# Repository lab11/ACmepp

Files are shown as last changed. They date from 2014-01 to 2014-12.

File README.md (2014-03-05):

AC Power Meters
===============

This repository contains code and hardware for a set of AC power meters.

ACme++
------

ACme++ is an updated version of the [ACme](http://acme.eecs.berkeley.edu) device.
The major change is a switch from the Epic platform (MSP430F1611 and CC2420) to
the CC2538 system on chip. Other changes include putting the relay on the phase
wire (instead of neutral) and a smaller AC-DC power supply.

While ACme++ is a wireless power meter in its own right, it was designed to be 
a prototype for the ultra-space-constrained PowerCube device.

PowerCube
---------

PowerCube is a one cubic inch power meter. It is designed to unobtrusively fit
on a power strip. This requires using six PCBs arranged in a cube with very
strategically placed components.

Software
--------

Software for the ACme++ is written on top of ContikiOS.

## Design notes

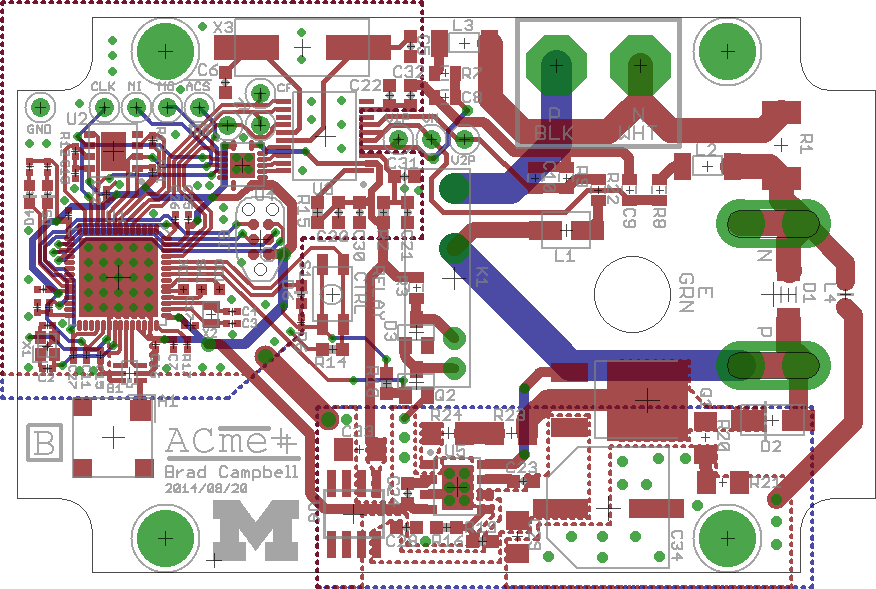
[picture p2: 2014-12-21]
hardware/ACme++/rev_b/ACme++_pcb.png

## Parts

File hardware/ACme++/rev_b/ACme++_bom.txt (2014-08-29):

# Bill of Materials
# Converted from ACme++_bom.xlsx
# Generated by bom_to_text.py

Qty  Value                           Device                          Package                          Parts                                        Description                                                       DIGIKEY             MOUSER                NEWARK   RICHARDSON_RFPD  McMASTER-CARR
1    FRACTUS-2.4GHZ-FR05-S1-N-0-001  FRACTUS-2.4GHZ-FR05-S1-N-0-001  FRACTUS-ANTENNA-FR05-S1-N-0-001  A1                                           Fractus Reach Xtend                                                                                                  FR05-S1-N-0001B  
1    2450BM15A0002                   2450BM15A0002                   2450BM                           B1                                           BALUN JTI MATCHED ZIGBEE                                          712-1536-1-ND                                                       
2    12pF                            CAPACITOR                       0402-CAP                         C1, C2                                       Capacitor                                                         445-1236-1-ND                                                       
2    22pF                            CAPACITOR                       0402-CAP                         C3, C4                                       Capacitor                                                         490-5868-1-ND                                                       
2    22pF                            CAP0603-CAP                     0603-CAP                         C5, C6                                       Capacitor                                                         445-1273-1-ND                                                       
1    220pF                           CAPACITOR                       0402-CAP                         C7                                           Capacitor                                                         445-1251-1-ND                                                       
3    33nF                            CAP0805                         0805-CAP                         C8, C9, C10                                  Capacitor                                                         478-1389-1-ND                                                       
9    0.1uF                           CAPACITOR                       0402-CAP                         C11, C12, C13, C14, C15, C16, C17, C18, C19  Capacitor                                                         445-1265-1-ND                                                       
5    0.1uF                           CAP0603-CAP                     0603-CAP                         C20, C21, C22, C23, C24                      Capacitor                                                         445-1316-1-ND                                                       
3    1uF                             CAPACITOR                       0402-CAP                         C25, C26, C27                                Capacitor                                                         445-4998-1-ND                                                       
1    1uF                             CAP0603-CAP                     0603-CAP                         C28                                          Capacitor                                                         445-5956-1-ND                                                       
1    1uF                             CAP1206                         1206-CAP                         C29                                          Capacitor                                                         445-1381-1-ND                                                       
3    10uF                            CAP0603-CAP                     0603-CAP                         C30, C31, C32                                Capacitor                                                         1276-1119-1-ND                                                      
1    47uF                            CAP1206                         1206-CAP                         C33                                          Capacitor                                                         399-5508-1-ND                                                       
1    470uF                           CAP_EEE-FP1E471AP               CAP_SM_10MM                      C34                                          Surface mount low ESR cap.                                        PCE4440CT-ND                                                        
1    SMAJ_TVS                        SMAJ_TVS                        DO214_TVS                        D1                                                                                                             SMAJ250CALFCT-ND                                                    
1    S1G                             S1G                             DO-214AC                         D2                                           Diode 400V 1A SMA                                                 S1GFSCT-ND                                                          
1    DIODE_MMBD914                   DIODE_MMBD914                   SOT-23                           D3                                           DIODE SML SIG 100V 0.2A SOT23-3                                   MMBD914FSCT-ND                                                      
1    RED                             LED0603                         LED-0603                         D4                                           LEDs                                                              160-1835-1-ND                                                       
1    GREEN                           LED0603                         LED-0603                         D5                                           LEDs                                                              160-1834-1-ND                                                       
1    BLUE                            LED0603                         LED-0603                         D6                                           LEDs                                                              160-1837-1-ND                                                       
1    S216S01F                        S216S01F                        RELAY_SX16S0X                    K1                                           RELAY SSR 240VAC 16A TRIAC 4-SIP                                  425-2413-5-ND       852-S216S01F          14N9591                   
1    35F0121-0SR-10                  35F0121-0SR-10                  35F0102                          L1                                           FERRITE 10A 42 OHMS @ 10 MHZ SMD                                  240-2520-1-ND                                                       
2    EMI_SUPRESSION_FERRITE_BEAD     EMI_SUPRESSION_FERRITE_BEAD     L1806                            L2, L3                                       FERRITE 300MA 150 OHM 1806 SMD                                    240-2418-1-ND                                                       
1    MPZ2012S300A                    MPZ2012S300A                    0805                             L4                                           FERRITE CHIP 30 OHM 6A 0805                                       445-1566-1-ND                                                       
1    STGD5NB120SZT4                  STGD5NB120SZT4                  DPAK                             Q1                                           5 A - 1200 V - low drop internally clamped IGBT                   497-4352-1-ND                                                       
1    FDV301N                         FDV301N                         SOT-23                           Q2                                                                                                             FDV301NCT-ND                                                        
1    0.001                           RESISTOR2512                    R2512                            R1                                           Resistor                                                          P1.0TCT-ND                                                          
1    10                              RESISTOR0603-RES                0603-RES                         R2                                           Resistor                                                          RHM10.0CFCT-ND                                                      
1    330                             RESISTOR0805-RES                0805-RES                         R3                                           Resistor                                                          RHM330KCT-ND                                                        
3    470                             RESISTOR                        0402-RES                         R4, R5, R6                                   Resistor                                                          RHM470BHCT-ND                                                       
3    1k                              RESISTOR0805-RES                0805-RES                         R7, R8, R9                                   Resistor                                                          P16058CT-ND                                                         
1    2.2k                            RESISTOR                        0402-RES                         R10                                          Resistor                                                          RHM2.2KCECT-ND                                                      
3    4.7k                            RESISTOR                        0402-RES                         R11, R12, R13                                Resistor                                                          RHM4.7KCECT-ND                                                      
2    10k                             RESISTOR0603-RES                0603-RES                         R14, R15                                     Resistor                                                          RHM10.0KCFCT-ND                                                     
1    12.4k                           RESISTOR0603-RES                0603-RES                         R16                                          Resistor                                                          RHM12.4KCFCT-ND                                                     
1    56k                             RESISTOR                        0402-RES                         R17                                          Resistor                                                          RHM56KBHCT-ND                                                       
1    100k                            RESISTOR0603-RES                0603-RES                         R18                                          Resistor                                                          RHM100KCGCT-ND                                                      
1    113k                            RESISTOR0603-RES                0603-RES                         R19                                          Resistor                                                          RHM113KCFCT-ND                                                      
2    200k                            RESISTOR1206                    1206-RES                         R20, R21                                     Resistor                                                          P200KALCT-ND                                                        
1    499k                            RESISTOR0805-RES                0805-RES                         R22                                          Resistor                                                          P499KCCT-ND                                                         
2    510k                            RESISTOR1206                    1206-RES                         R23, R24                                     Resistor                                                          P510KALCT-ND                                                        
1    EVQP2                           EVQP2                           EVQP2                            S1                                                                                                             P11084SCT-ND                                                        
1    TEST_POINT_0.040IN              TEST_POINT_0.040IN              TESTPOINT_0.040IN                TP1                                          0.040in Test Point Black                                          5001K-ND                                                            
3    TEST_POINT_0.040IN              TEST_POINT_0.040IN              TESTPOINT_0.040IN                TP2, TP3, TP4                                0.040in Test Point Blue                                           5117K-ND                                                            
1    TEST_POINT_0.040IN              TEST_POINT_0.040IN              TESTPOINT_0.040IN                TP5                                          0.040in Test Point Yellow                                         5004K-ND                                                            
3    TEST_POINT_0.040IN              TEST_POINT_0.040IN              TESTPOINT_0.040IN                TP6, TP7, TP8                                0.040in Test Point Green                                          5116K-ND                                                            
3    TEST_POINT_0.040IN              TEST_POINT_0.040IN              TESTPOINT_0.040IN                TP9, TP10, TP11                              0.040in Test Point Orange                                         5003K-ND                                                            
1    CC2538                          CC2538                          S-PVQFN-N56                      U1                                           A Powerful System-On-Chip for 2.4-GHz IEEE 802.15.4, 6LoWPAN      296-35797-1-ND      595-CC2538SF53RTQT    87W7713                   
1    FM25LBTDFN-8                    FM25LBTDFN-8                    TDFN-8                           U2                                           IC FRAM 4KBIT 10MHZ 8SOIC                                         FM25L04B-DGRA-ND    877-FM25L04B-DG                                 
1    ADE7753                         ADE7753                         SSOP-20                          U3                                           Single-Phase Multifunction Metering IC                            ADE7753ARSZRLCT-ND  584-ADE7753ARSZR      59K0984                   
1    TXB0104RGY                      TXB0104RGY                      S-PVQFN-N14                      U4                                           4-BIT BIDIRECTIONAL VOLTAGE-LEVEL TRANSLATOR                      296-21930-1-ND                                                      
1    SR086SG-G                       SR086SG-G                       SR086                            U5                                           Adjustable Off-Line Inductorless Switching Regulator                                  689-SR086SG-G                                   
1    TDA3664AT                       TDA3664AT                       SOIC_8                           U6                                           Very low dropout voltage/quiescent current 5 V voltage regulator  568-3310-1-ND       771-TDA3664ATN1118                              
1    EPSON-FA-128                    EPSON-FA-128                    FA-128                           X1                                           MHz RANGE CRYSTAL UNIT                                            SER3800CT-ND        732-FA128-32F20X-K3                             
1    FC-12M32.7680KA-A3              FC-12M32.7680KA-A3              FC-12M                           X2                                           kHz RANGE CRYSTAL UNIT                                            SER3672CT-ND        732-FC-12M-32.76KAA3                            
1    ECS-35-17-5PX-TR                ECS-35-17-5PX-TR                CSM-7X                           X3                                           CRYSTAL 3.579545MHZ 17PF SMD                                      XC1234CT-ND         520-CSM357-17-X                                 
1    ENCLOSURE                       PPB-11860-BK                                                                                                  BOX ABS 3.09X2.09X1.65" BLK                                       377-1709-ND                                                         
0    ENCLOSURE                       PPB-11860-WT                                                                                                  BOX ABS 3.09X2.09X1.65" WHT                                       377-1710-ND                                                         
1    SOCKET                          739W-X2/03                                                                                                    OUTLET PWR NEMA 5-15R SNAPIN/IDC                                  Q228-ND                                                             
0    14AWG Black                     6717 BK005                                                                                                    HOOK-UP STRND 14AWG BLACK 100'                                    6717 BK005-ND                                                       
0    14AWG Green                     6717 GR005                                                                                                    HOOK-UP STRND 14AWG GREEN 100'                                    6717 GR005-ND                                                       
0    14AWG White                     6717 WH005                                                                                                    HOOK-UP STRND 14AWG WHITE 100'                                    6717 WH005-ND                                                       
4    #4 Screw                                                                                                                                      #4 3/16" Panhead Self-Tapping Screws                                                                                                  92470a106

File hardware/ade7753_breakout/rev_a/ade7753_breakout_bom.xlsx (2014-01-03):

Part | Value | Device | Package | Description | Distributor | Quantity | Part# | Custom Part# | Price | min price break | Notes
C1, C2, C3, C4 | 33n | CAP0805 | C0805 | Capacitor | DigiKey | 4 | 478-3769-1-ND |  | 0.363 | 100
C5, C7, C9 | 0.1u | CAP0805 | C0805 | Capacitor | DigiKey | 3 | 478-5721-1-ND |  | 0.209 | 100
C6, C8, C10 | 10u | CAP0805 | C0805 | Capacitor | DigiKey | 3 | 478-5165-1-ND |  | 0.33 | 100
C11, C12 | 22p | C-USC0603 | C0603 | CAPACITOR, America | DigiKey | 2 | 478-5771-1-ND |  | 0.66 | 100
J1, J2 |  | M02PTH | 1X02 | Header 2 | DigiKey | 2 | A31112-ND |  | 0.2 | 25
J3 | M10" | M10" | 1X10 | Header 10 | DigiKey | 1 | A30844-ND |  | 0.54 | 25
R1, R2, R3, R4 | 1k | R-US_R0603 | R0603 | RESISTOR, American | DigiKey | 4 | RG16P1.0KBCT-ND |  | 0.409 | 50
R5 | 10 | R-US_R0603 | R0603 | RESISTOR, American | DigiKey | 1 | CRT0603-BY-10R0ELFCT-ND |  | 0.25 | 10
R6, R7 | 499k | R-US_R0805 | R0805 | RESISTOR, American | DigiKey | 2 | RG20P499KBCT-ND |  | 0.409 | 100
U1 | ADE7753 | ADE7753 | SSOP20 |  | DigiKey | 1 | ADE7753ARSZ-ND |  | 4.31 | 25
Y1 | 3.579 MHz | CRYSTALHC49S | HC49/S | CRYSTAL | DigiKey | 1 | 887-1000-ND |  | 0.46 | 100

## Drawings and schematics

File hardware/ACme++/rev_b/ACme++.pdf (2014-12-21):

# Programmer Header

## TC2030-CC2538-BL-NL

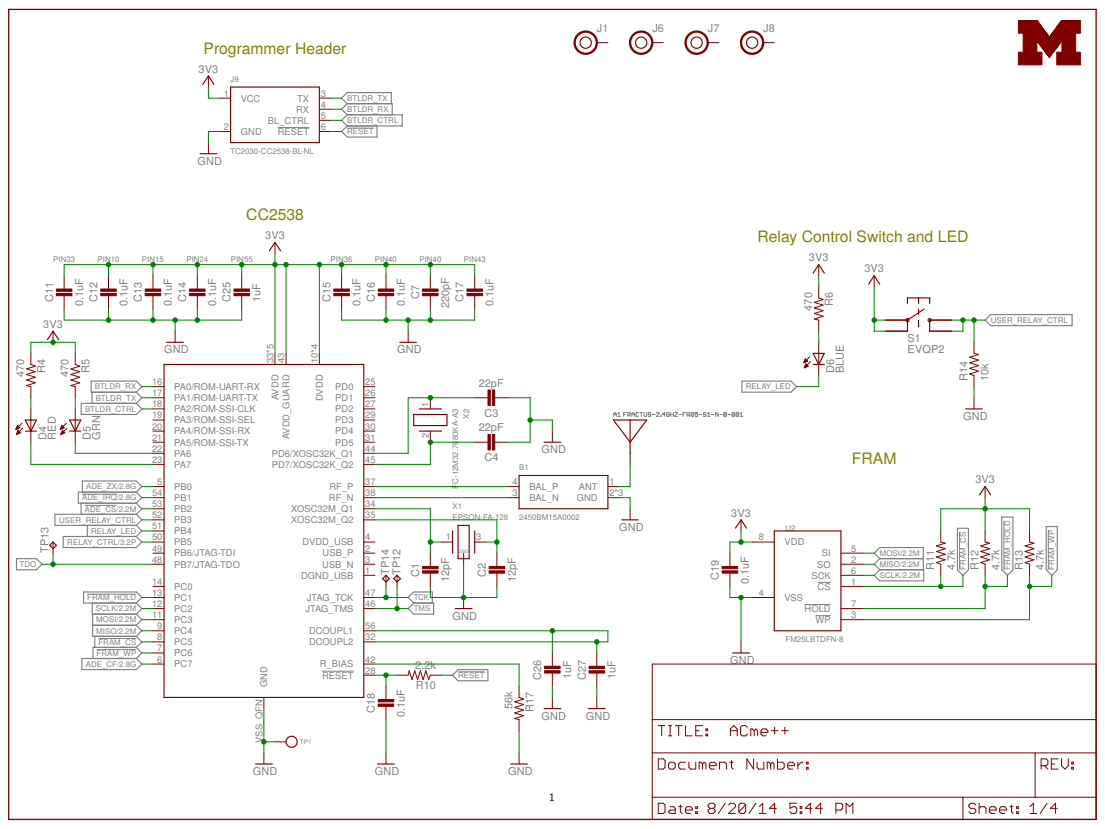
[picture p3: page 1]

Relay Control Switch and LED

32
42

# ADE7753 Power Measurement

5V0

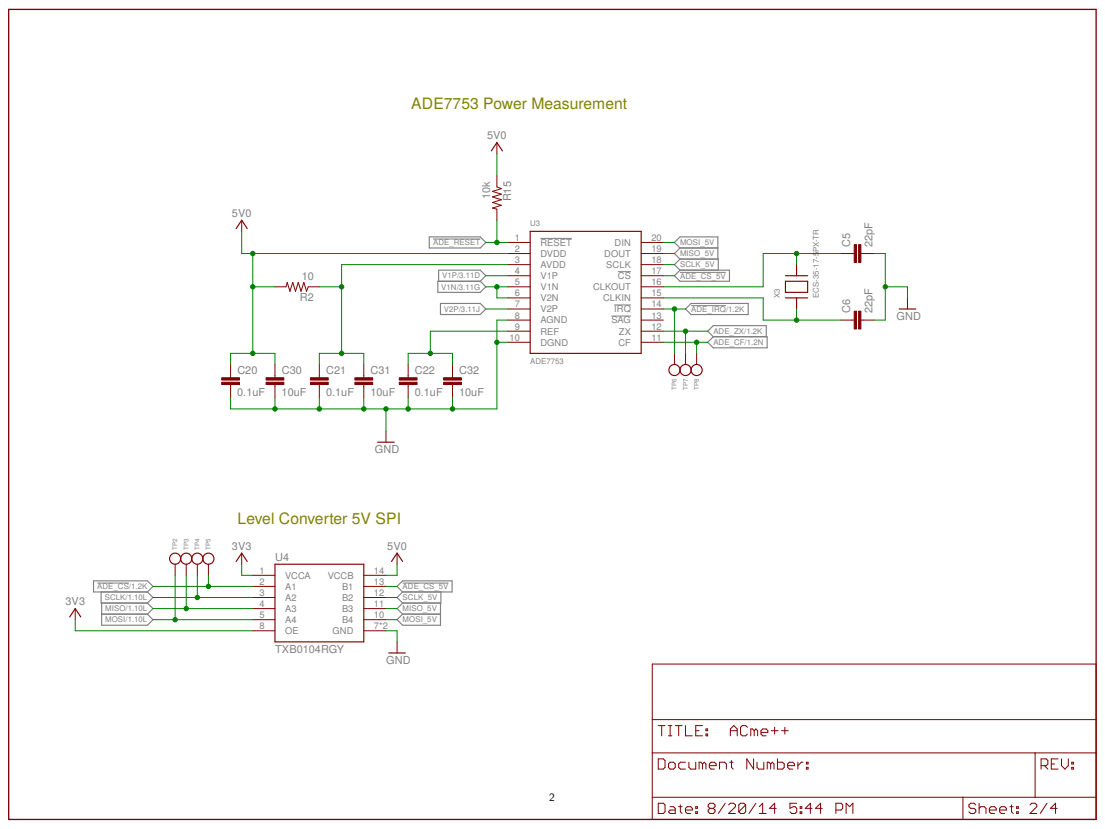
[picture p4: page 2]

# Sense Resistor

# Metering Conditioning

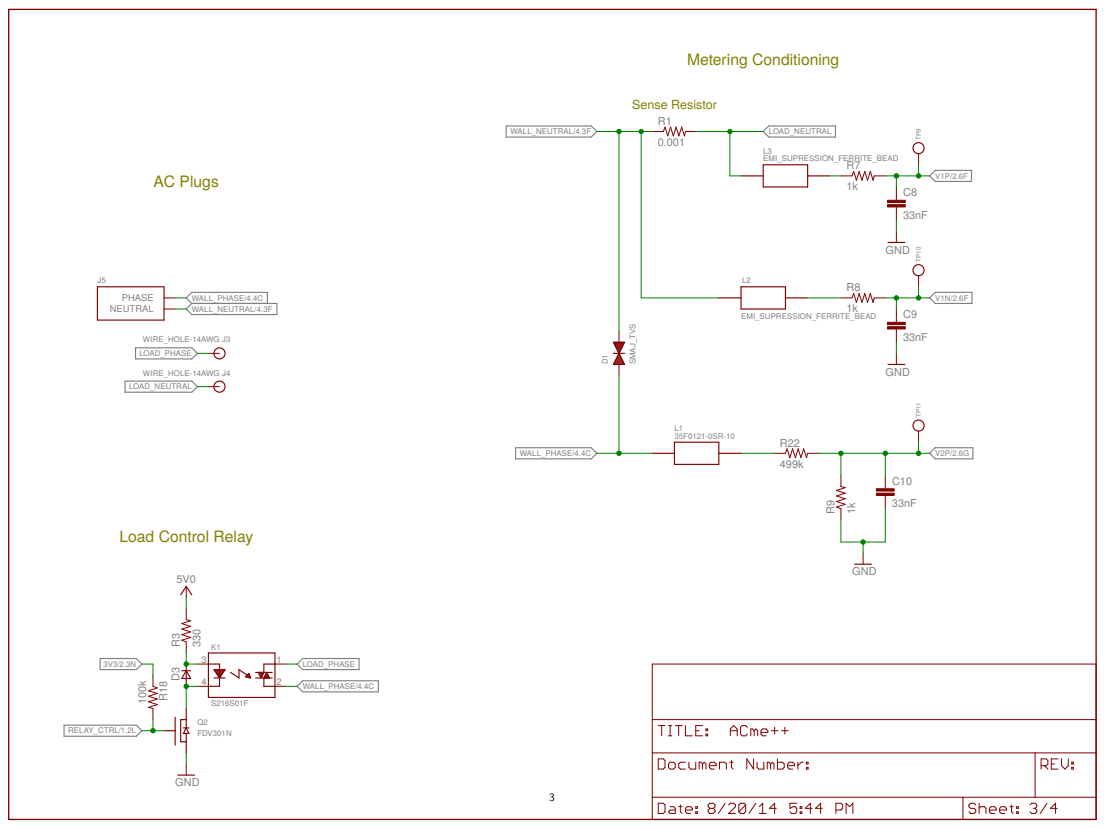
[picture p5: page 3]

## Nominally 12.6 V AC-DC Converter

## Note: Need half-wave rectifier here

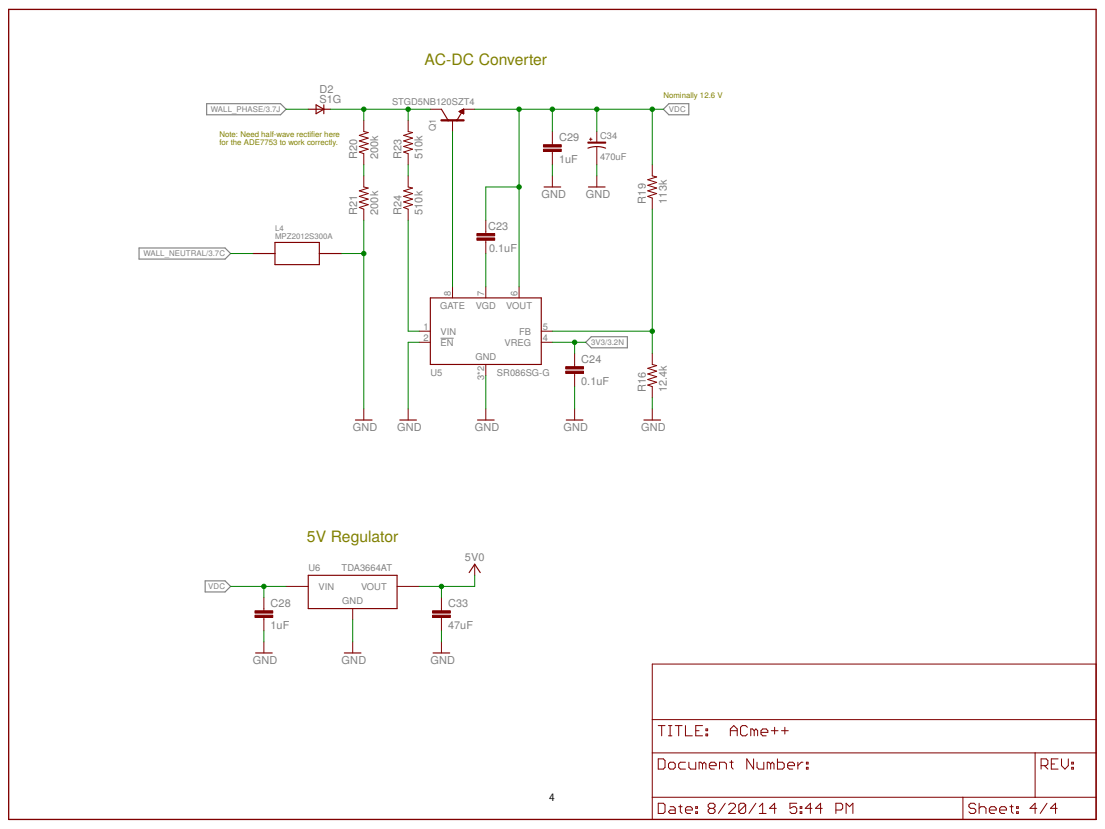
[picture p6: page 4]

for the ADE7753 to work correctly.

# Top and Bottom Layers

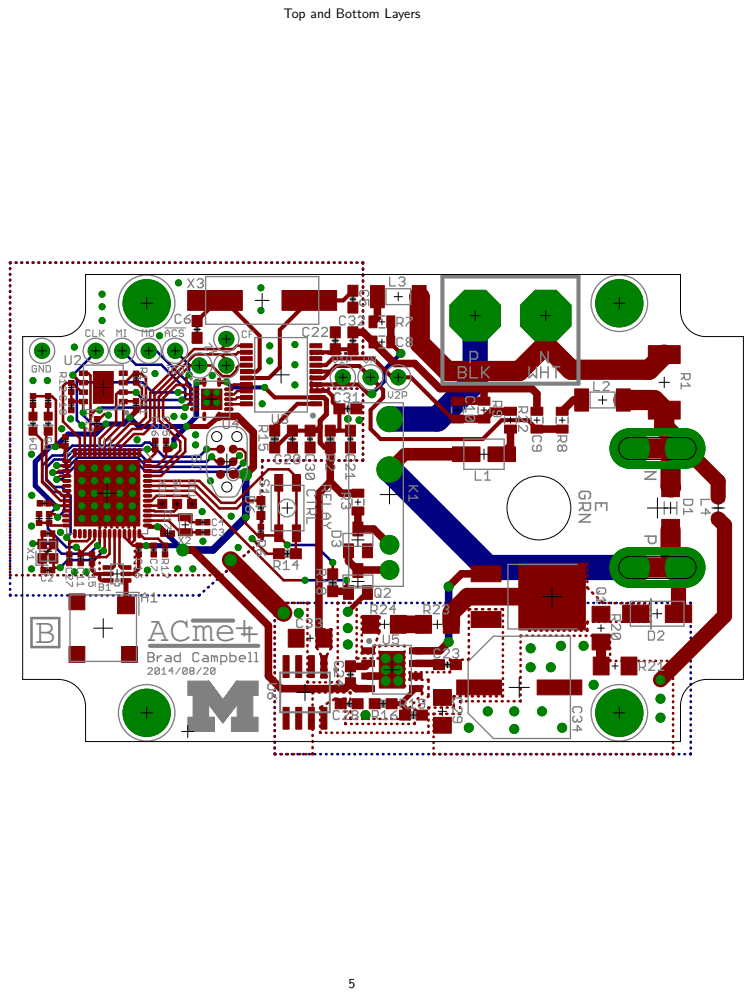
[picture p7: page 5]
ACme+

# Top Layer

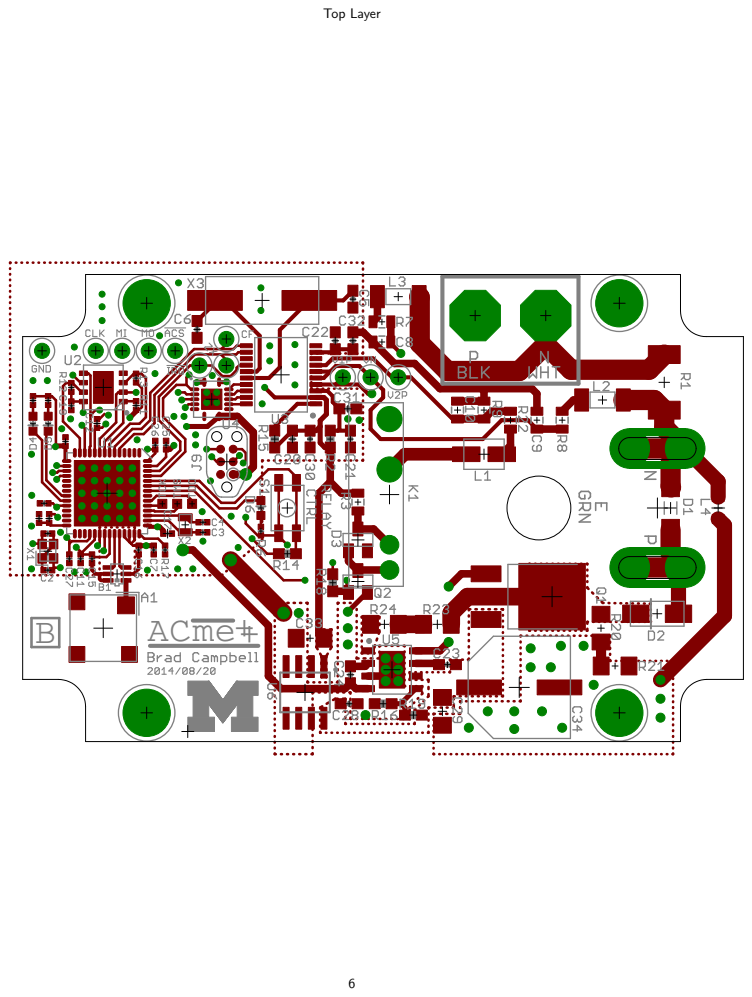
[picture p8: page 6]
ACme+

# Bottom Layer

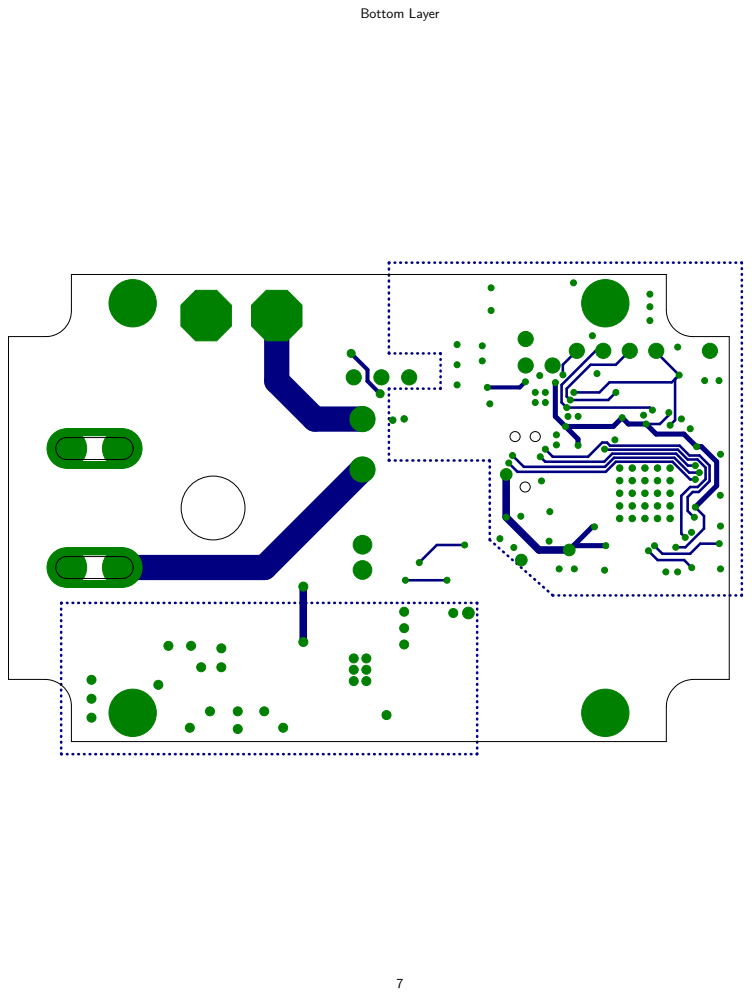
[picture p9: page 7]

# Top Copper Layer

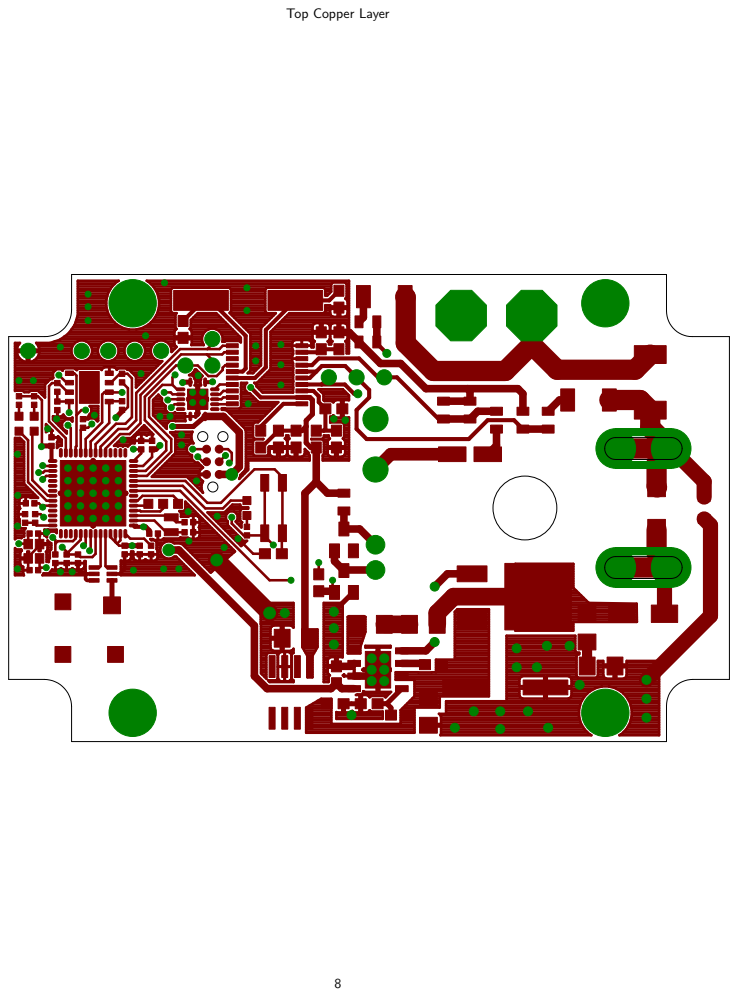
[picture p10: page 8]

# Bottom Copper Layer

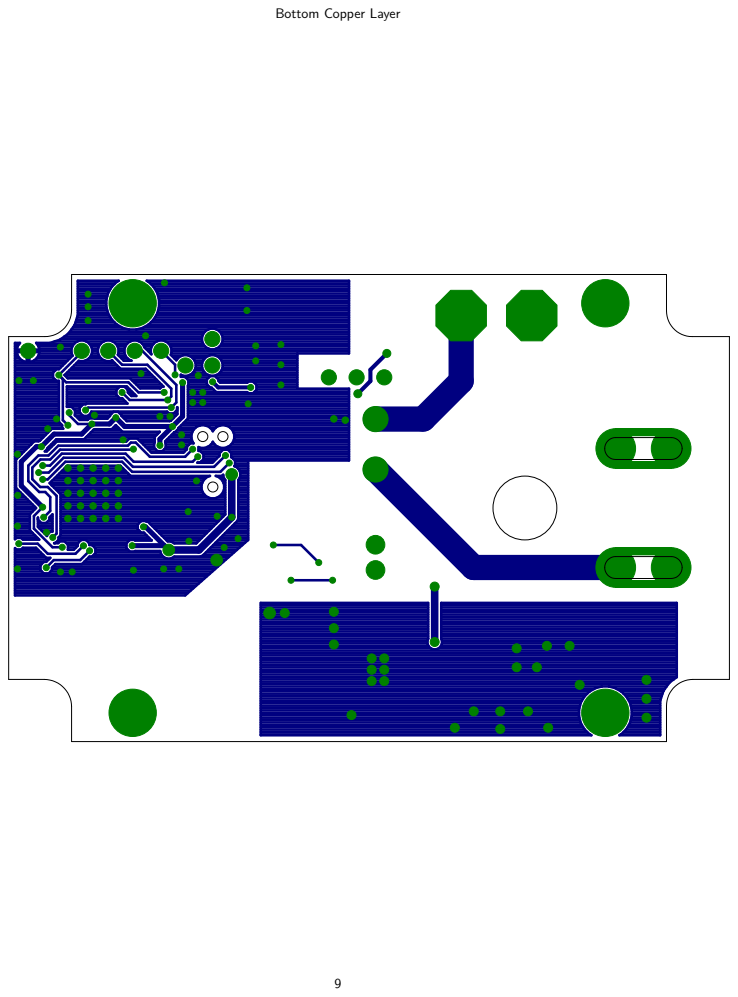
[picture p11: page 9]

# Top Paste Layer with Silkscreen

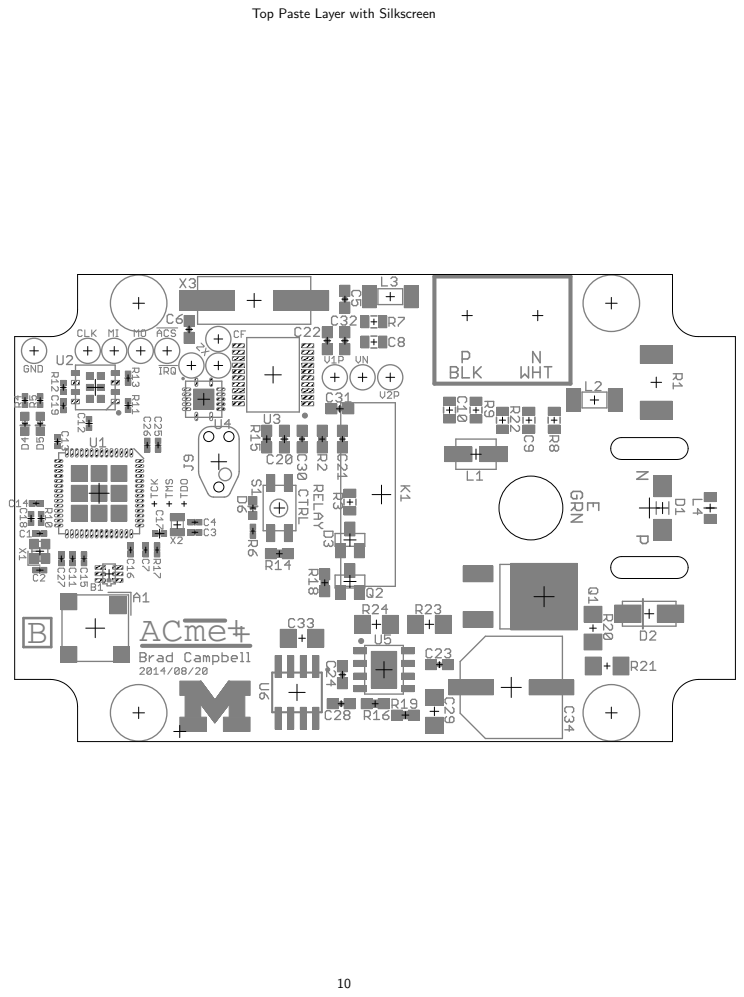
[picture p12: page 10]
ACme+

# Bottom Paste Layer with Silkscreen

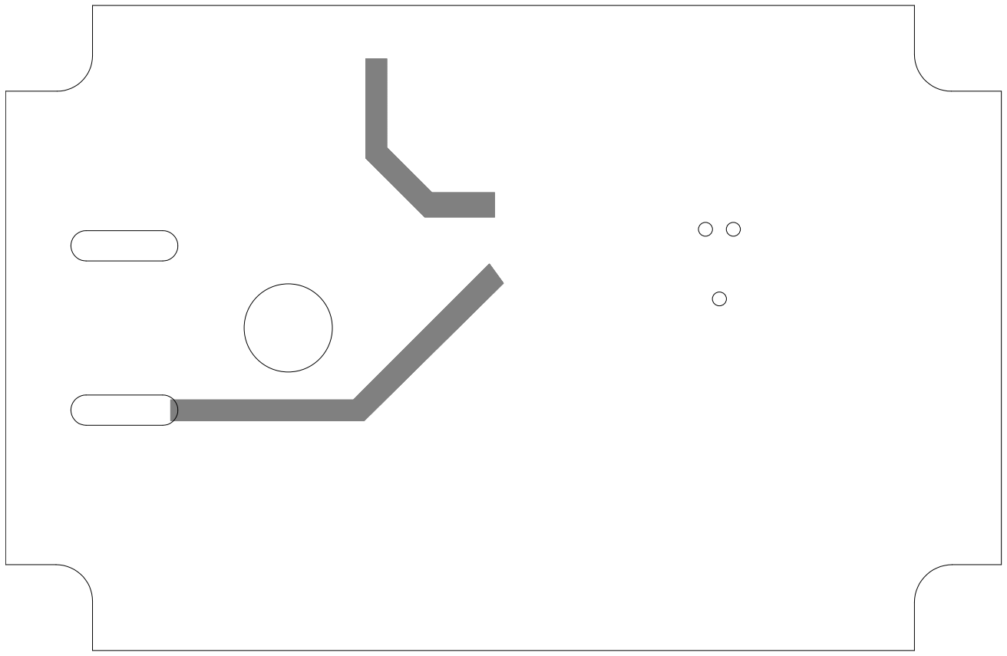
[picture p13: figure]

# Top and Bottom Layers 1:1 Scale

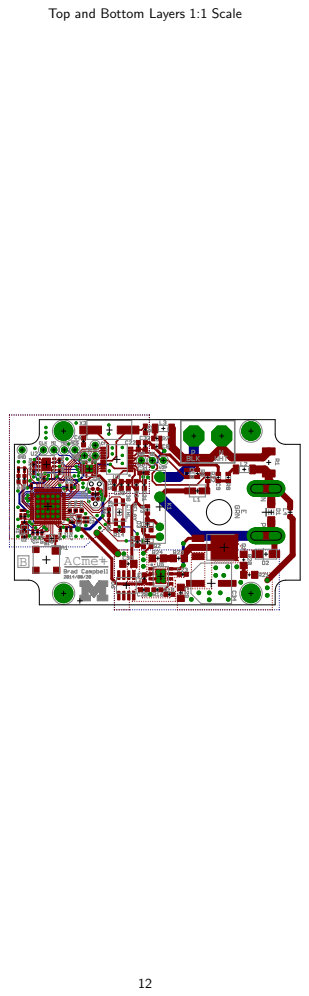
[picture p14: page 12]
ACme+

# Top Layer 1:1 Scale


# Bottom Copper Layer 1:1 Scale


Qty | Value | Device | Package | Parts | Description | DIGIKEY | MOUSER | NEWARK RICHARDSON_RFPD McMASTER-CARR
| 1 FRACTUS-2.4GHZ-FR05-S1-N-0-001 | FRACTUS-2.4GHZ-FR05-S1-N-0-001 | FRACTUS-ANTENNA-FR05-S1-N-0-001 | A1 | Fractus Reach Xtend | | | FR05-S1-N-0001B
| 1 2450BM15A0002 | 2450BM15A0002 | 2450BM | B1 | BALUN JTI MATCHED ZIGBEE | 712-1536-1-ND
| 2 12pF | CAPACITOR | 0402-CAP | C1, C2 | Capacitor | 445-1236-1-ND
| 2 22pF | CAPACITOR | 0402-CAP | C3, C4 | Capacitor | 490-5868-1-ND
| 2 22pF | CAP0603-CAP | 0603-CAP | C5, C6 | Capacitor | 445-1273-1-ND
| 1 220pF | CAPACITOR | 0402-CAP | C7 | Capacitor | 445-1251-1-ND
| 3 33nF | CAP0805 | 0805-CAP | C8, C9, C10 | Capacitor | 478-1389-1-ND
| 9 0.1uF | CAPACITOR | 0402-CAP | C11, C12, C13, C14, C15, C16, C17, C18, C19 | Capacitor | 445-1265-1-ND
| 5 0.1uF | CAP0603-CAP | 0603-CAP | C20, C21, C22, C23, C24 | Capacitor | 445-1316-1-ND
| 3 1uF | CAPACITOR | 0402-CAP | C25, C26, C27 | Capacitor | 445-4998-1-ND
| 1 1uF | CAP0603-CAP | 0603-CAP | C28 | Capacitor | 445-5956-1-ND
| 1 1uF | CAP1206 | 1206-CAP | C29 | Capacitor | 445-1381-1-ND
| 3 10uF | CAP0603-CAP | 0603-CAP | C30, C31, C32 | Capacitor | 1276-1119-1-ND
| 1 47uF | CAP1206 | 1206-CAP | C33 | Capacitor | 399-5508-1-ND
| 1 470uF | CAP_EEE-FP1E471AP | CAP_SM_10MM | C34 | Surface mount low ESR cap. | PCE4440CT-ND
| 1 SMAJ_TVS | SMAJ_TVS | DO214_TVS | D1 | | SMAJ250CALFCT-ND
| 1 S1G | S1G | DO-214AC | D2 | Diode 400V 1A SMA | S1GFSCT-ND
| 1 DIODE_MMBD914 | DIODE_MMBD914 | SOT-23 | D3 | DIODE SML SIG 100V 0.2A SOT23-3 | MMBD914FSCT-ND
| 1 RED | LED0603 | LED-0603 | D4 | LEDs | 160-1835-1-ND
| 1 GREEN | LED0603 | LED-0603 | D5 | LEDs | 160-1834-1-ND
| 1 BLUE | LED0603 | LED-0603 | D6 | LEDs | 160-1837-1-ND
| 1 S216S01F | S216S01F | RELAY_SX16S0X | K1 | RELAY SSR 240VAC 16A TRIAC 4-SIP | 425-2413-5-ND | 852-S216S01F | 14N9591
| 1 35F0121-0SR-10 | 35F0121-0SR-10 | 35F0102 | L1 | FERRITE 10A 42 OHMS @ 10 MHZ SMD | 240-2520-1-ND
| 2 EMI_SUPRESSION_FERRITE_BEAD | EMI_SUPRESSION_FERRITE_BEAD | L1806 | L2, L3 | FERRITE 300MA 150 OHM 1806 SMD | 240-2418-1-ND
| 1 MPZ2012S300A | MPZ2012S300A | 0805 | L4 | FERRITE CHIP 30 OHM 6A 0805 | 445-1566-1-ND
| 1 STGD5NB120SZT4 | STGD5NB120SZT4 | DPAK | Q1 | 5 A - 1200 V - low drop internally clamped IGBT | 497-4352-1-ND
| 1 FDV301N | FDV301N | SOT-23 | Q2 | | FDV301NCT-ND
| 1 0.001 | RESISTOR2512 | R2512 | R1 | Resistor | P1.0TCT-ND
| 1 10 | RESISTOR0603-RES | 0603-RES | R2 | Resistor | RHM10.0CFCT-ND
| 1 330 | RESISTOR0805-RES | 0805-RES | R3 | Resistor | RHM330KCT-ND
| 3 470 | RESISTOR | 0402-RES | R4, R5, R6 | Resistor | RHM470BHCT-ND
| 3 1k | RESISTOR0805-RES | 0805-RES | R7, R8, R9 | Resistor | P16058CT-ND
| 1 2.2k | RESISTOR | 0402-RES | R10 | Resistor | RHM2.2KCECT-ND
| 3 4.7k | RESISTOR | 0402-RES | R11, R12, R13 | Resistor | RHM4.7KCECT-ND
| 2 10k | RESISTOR0603-RES | 0603-RES | R14, R15 | Resistor | RHM10.0KCFCT-ND
| 1 12.4k | RESISTOR0603-RES | 0603-RES | R16 | Resistor | RHM12.4KCFCT-ND
| 1 56k | RESISTOR | 0402-RES | R17 | Resistor | RHM56KBHCT-ND
| 1 100k | RESISTOR0603-RES | 0603-RES | R18 | Resistor | RHM100KCGCT-ND
| 1 113k | RESISTOR0603-RES | 0603-RES | R19 | Resistor | RHM113KCFCT-ND
| 2 200k | RESISTOR1206 | 1206-RES | R20, R21 | Resistor | P200KALCT-ND
| 1 499k | RESISTOR0805-RES | 0805-RES | R22 | Resistor | P499KCCT-ND
| 2 510k | RESISTOR1206 | 1206-RES | R23, R24 | Resistor | P510KALCT-ND
| 1 EVQP2 | EVQP2 | EVQP2 | S1 | | P11084SCT-ND
| 1 TEST_POINT_0.040IN | TEST_POINT_0.040IN | TESTPOINT_0.040IN | TP1 | 0.040in Test Point Black | 5001K-ND
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

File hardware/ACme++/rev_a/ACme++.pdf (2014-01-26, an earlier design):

# Programmer Header

DS2411


Relay Control Switch and LED

32
42

# ADE7753 Power Measurement

5V0


# Sense Resistor

# Metering Conditioning


## Nominally 12.6 V AC-DC Converter

# CD2320-BB11000


# Top and Bottom Layers

ACme+

# Top Layer

ACme+

# Bottom Layer


# Top Copper Layer


# Bottom Copper Layer


# Top Paste Layer with Silkscreen

ACme+

# Bottom Paste Layer with Silkscreen


# Top and Bottom Layers 1:1 Scale

ACme+

# Top Layer 1:1 Scale


# Bottom Copper Layer 1:1 Scale


Qty | Value | Device | Package | Parts | Description | DIGIKEY | MOUSER | NEWARK RICHARDSON_RFPD McMASTER-CARR
| 1 FRACTUS-2.4GHZ-FR05-S1-N-0-001 | FRACTUS-2.4GHZ-FR05-S1-N-0-001 | FRACTUS-ANTENNA-FR05-S1-N-0-001 | A1 | Fractus Reach Xtend | | | FR05-S1-N-0001B
| 1 2450BM15A0002 | 2450BM15A0002 | 2450BM | B1 | BALUN JTI MATCHED ZIGBEE | 712-1536-1-ND
| 2 12pF | CAPACITOR | 0402-CAP | C1, C2 | Capacitor | 445-1236-1-ND
| 2 22pF | CAPACITOR | 0402-CAP | C3, C4 | Capacitor | 490-5868-1-ND
| 2 22pF | CAP0603-CAP | 0603-CAP | C5, C6 | Capacitor | 445-1273-1-ND
| 1 220pF | CAPACITOR | 0402-CAP | C7 | Capacitor | 445-1251-1-ND
| 3 33nF | CAP0805 | 0805-CAP | C8, C9, C10 | Capacitor | 478-1389-1-ND
9 0.1uF | CAPACITOR | 0402-CAP | C11, C12, C13, C14, C15, C16, C17, C18, C19 Capacitor | 445-1265-1-ND
| 5 0.1uF | CAP0603-CAP | 0603-CAP | C20, C21, C22, C23, C24 | Capacitor | 445-1316-1-ND
| 3 1uF | CAPACITOR | 0402-CAP | C25, C26, C27 | Capacitor | 445-4998-1-ND
| 1 1uF | CAP0603-CAP | 0603-CAP | C28 | Capacitor | 445-5956-1-ND
| 1 1uF | CAP1206 | 1206-CAP | C29 | Capacitor | 445-1381-1-ND
| 3 10uF | CAP0603-CAP | 0603-CAP | C30, C31, C32 | Capacitor | 1276-1119-1-ND
| 1 47uF | CAP1206 | 1206-CAP | C33 | Capacitor | 399-5508-1-ND
| 1 470uF | CAP_EEE-FP1E471AP | CAP_SM_10MM | C34 | Surface mount low ESR cap. | PCE4440CT-ND
| 1 SMAJ_TVS | SMAJ_TVS | DO214_TVS | D1 | | SMAJ250CALFCT-ND
| 1 CD2320-BB11000 | CD2320-BB11000 | CD2320 | D2 | Bridge rectifier | CD2320-B11000CT-ND
| 1 DIODE_MMBD914 | DIODE_MMBD914 | SOT-23 | D3 | DIODE SML SIG 100V 0.2A SOT23-3 | MMBD914FSCT-ND
| 1 RED | LED0603 | LED-0603 | D4 | LEDs | 160-1835-1-ND
| 1 GREEN | LED0603 | LED-0603 | D5 | LEDs | 160-1834-1-ND
| 1 BLUE | LED0603 | LED-0603 | D6 | LEDs | 160-1837-1-ND
| 1 AC-PLUG | AC-PLUG | AC_MALE_PINS | J1 | For use with Bud Industries Box: 377-1709-ND
| 1 TC2030-CTX-NL | TC2030-CTX-NL | TC2030-IDC-NL | J2 | Tag Connect footprint for ARM JTAG.
| 3 WIRE_HOLE-14AWG | WIRE_HOLE-14AWG | WIRE_HOLE-14AWG | J3, J4, J5 | Solder point for 14AWG wire
| 1 S216S01F | S216S01F | RELAY_SX16S0X | K1 | RELAY SSR 240VAC 16A TRIAC 4-SIP | 425-2413-5-ND | 852-S216S01F | 14N9591
| 1 35F0121-0SR-10 | 35F0121-0SR-10 | 35F0102 | L1 | FERRITE 10A 42 OHMS @ 10 MHZ SMD | 240-2520-1-ND
| 2 EMI_SUPRESSION_FERRITE_BEAD | EMI_SUPRESSION_FERRITE_BEAD | L1806 | L2, L3 | FERRITE 300MA 150 OHM 1806 SMD | 240-2418-1-ND
| 1 STGD5NB120SZT4 | STGD5NB120SZT4 | DPAK | Q1 | 5 A - 1200 V - low drop internally clamped IGBT | 497-4352-1-ND
| 1 FDV301N | FDV301N | SOT-23 | Q2 | | FDV301NCT-ND
| 1 0.001 | RESISTOR2512 | R2512 | R1 | Resistor | P1.0TCT-ND
| 1 10 | RESISTOR0603-RES | 0603-RES | R2 | Resistor | RHM10.0CFCT-ND
| 1 330 | RESISTOR0805-RES | 0805-RES | R3 | Resistor | RHM330KCT-ND
| 3 470 | RESISTOR | 0402-RES | R4, R5, R6 | Resistor | RHM470BHCT-ND
| 3 1k | RESISTOR0805-RES | 0805-RES | R7, R8, R9 | Resistor | P16058CT-ND
| 2 2.2k | RESISTOR | 0402-RES | R10, R11 | Resistor | RHM2.2KCECT-ND
| 3 4.7k | RESISTOR | 0402-RES | R12, R13, R14 | Resistor | RHM4.7KCECT-ND
| 2 10k | RESISTOR0603-RES | 0603-RES | R15, R16 | Resistor | RHM10.0KCFCT-ND
| 1 12.4k | RESISTOR0603-RES | 0603-RES | R17 | Resistor | RHM12.4KCFCT-ND
| 1 56k | RESISTOR | 0402-RES | R18 | Resistor | RHM56KBHCT-ND
| 1 100k | RESISTOR0603-RES | 0603-RES | R19 | Resistor | RHM100KCGCT-ND
| 1 113k | RESISTOR0603-RES | 0603-RES | R20 | Resistor | RHM113KCFCT-ND
| 2 200k | RESISTOR1206 | 1206-RES | R21, R22 | Resistor | P200KALCT-ND
| 1 499k | RESISTOR0805-RES | 0805-RES | R23 | Resistor | P499KCCT-ND
| 2 510k | RESISTOR1206 | 1206-RES | R24, R25 | Resistor | P510KALCT-ND
| 1 EVQP2 | EVQP2 | EVQP2 | S1 | | P11084SCT-ND
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

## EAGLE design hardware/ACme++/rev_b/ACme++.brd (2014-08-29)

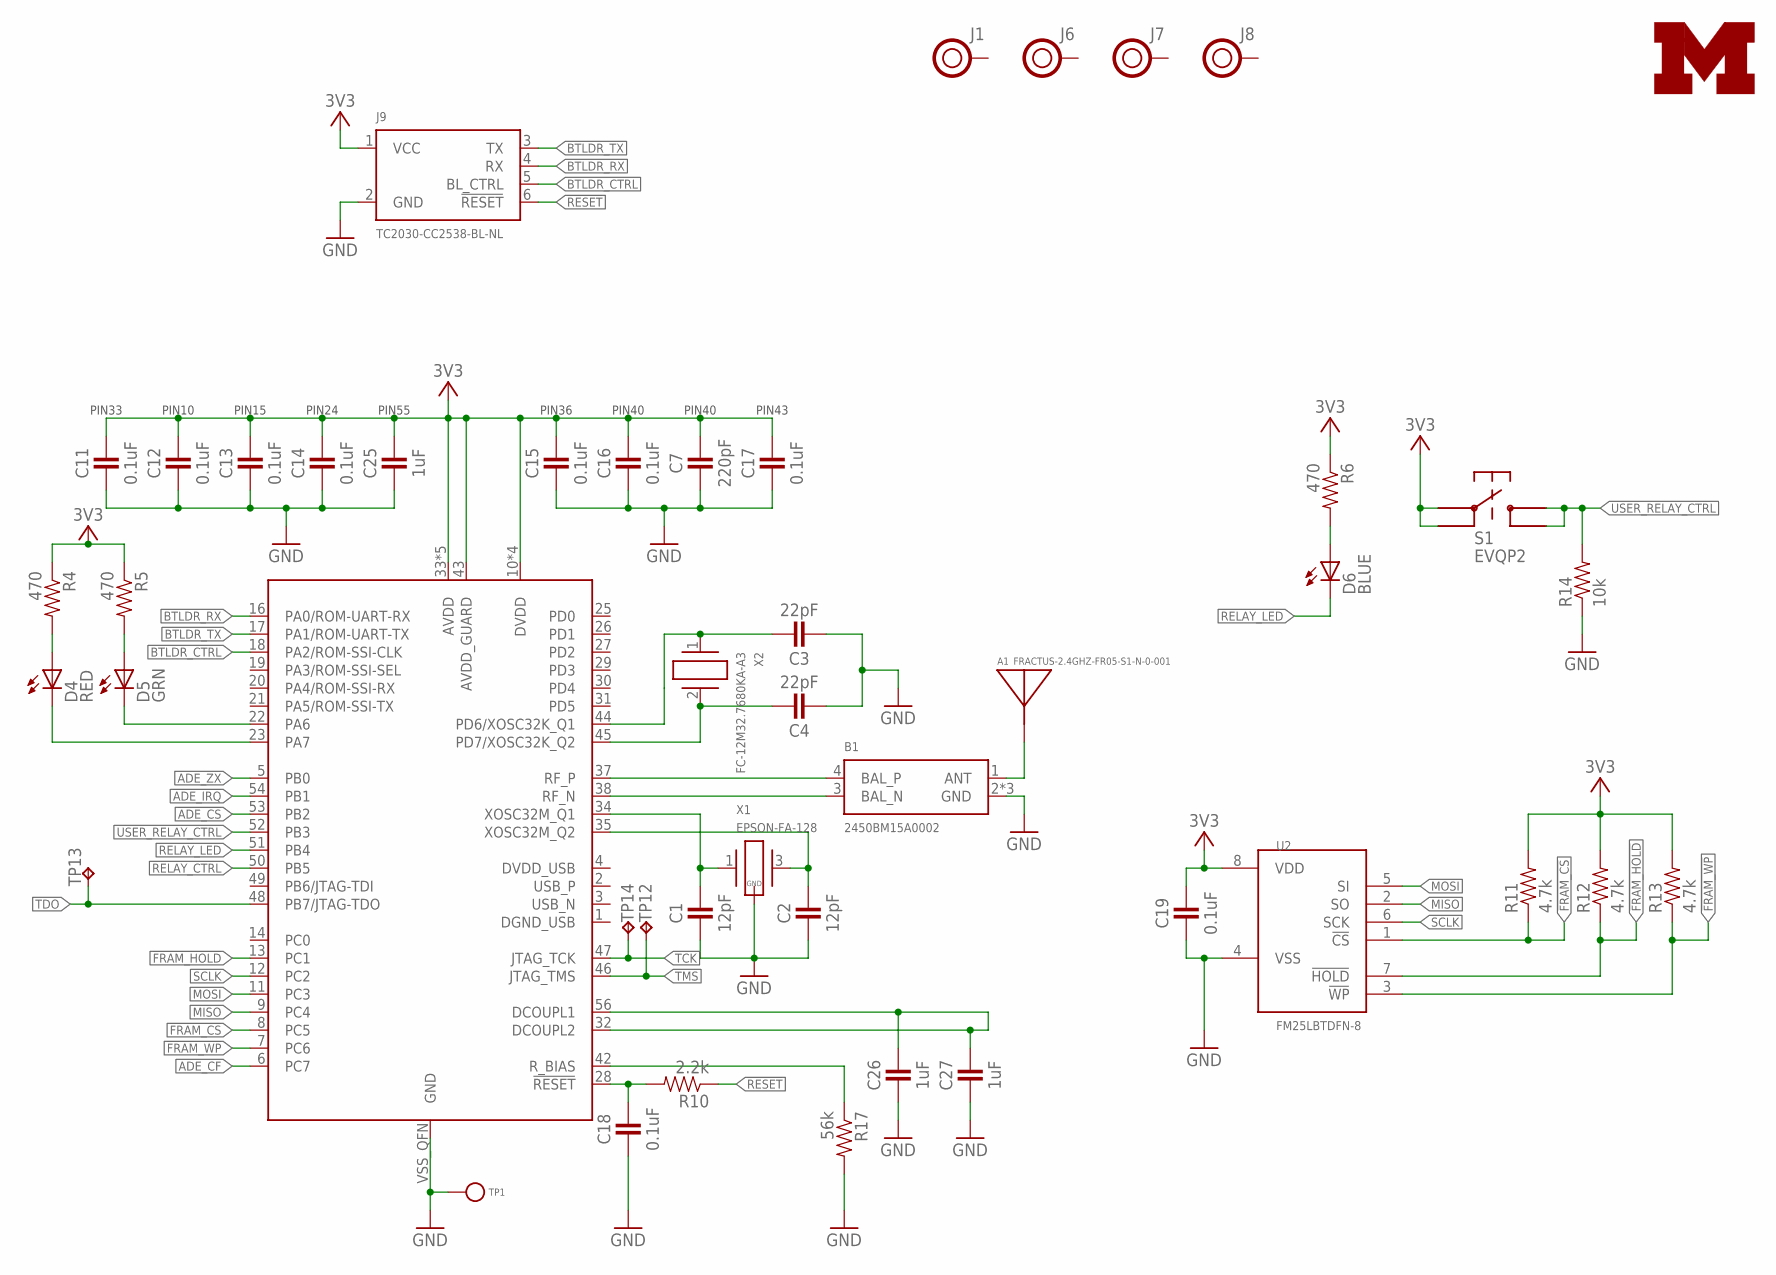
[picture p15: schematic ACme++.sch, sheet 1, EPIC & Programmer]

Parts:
A1: FRACTUS-2.4GHZ-FR05-S1-N-0-001; FRACTUS-ANTENNA-FR05-S1-N-0-001
B1: 2450BM15A0002; 2450BM
C1, C2: 12pF; 0402_CAP; DIGIKEY 445-1236-1-ND
C3, C4: 22pF; 0402_CAP; DIGIKEY 490-5868-1-ND
C7: 220pF; 0402_CAP; DIGIKEY 445-1251-1-ND
C11, C12, C13, C14, C15, C16, C17, C18, C19: 0.1uF; 0402_CAP; DIGIKEY 445-1265-1-ND
C25, C26, C27: 1uF; 0402_CAP; DIGIKEY 445-4998-1-ND
D4: RED; LED-0603; DIGIKEY 160-1835-1-ND
D5: GRN; LED-0603; DIGIKEY 160-1834-1-ND
D6: BLUE; LED-0603; DIGIKEY 160-1837-1-ND
J1, J6, J7, J8: HOLE; HOLE-0.125
J9: TC2030-CC2538-BL-NL; TC2030-IDC-NL
R4, R5, R6: 470; 0402_RES; DIGIKEY RHM470BHCT-ND
R10: 2.2k; 0402_RES; DIGIKEY RHM2.2KCECT-ND
R11, R12, R13: 4.7k; 0402_RES; DIGIKEY RHM4.7KCECT-ND
R14: 10k; 0603-RES; DIGIKEY RHM10.0KCFCT-ND
R17: 56k; 0402_RES; DIGIKEY RHM56KBHCT-ND
S1: EVQP2; DIGIKEY P11084SCT-ND
TP1: TEST_POINT_0.040IN; TESTPOINT_0.040IN
TP12, TP13, TP14: TPTP09SQ; TP09SQ
U1: CC2538; S-PVQFN-N56
U2: FM25LBTDFN-8; TDFN-8; DIGIKEY FM25L04B-DGRA-ND
U$3: UMICH_SOLID_MEDIUM; UMICH_SOLID_200MIL
X1: EPSON-FA-128; FA-128; DIGIKEY SER3800CT-ND
X2: FC-12M32.7680KA-A3; FC-12M

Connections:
3V3: C7.1, C11.1, C12.1, C13.1, C14.1, C15.1, C16.1, C17.1, C19.1, C25.1, J9.1 (VCC), R4.1, R5.1, R6.1, R11.2, R12.2, R13.2, S1.P$1, S1.P$3, U1.10 (DVDD), U1.15 (DVDD), U1.24 (DVDD), U1.33 (AVDD), U1.36 (AVDD), U1.39 (AVDD), U1.40 (AVDD), U1.41 (AVDD), U1.43 (AVDD_GUARD), U1.55 (DVDD), U2.8 (VDD); also elsewhere on the board
!ADE_CS: U1.53 (PB2); also elsewhere on the board
!ADE_IRQ: U1.54 (PB1); also elsewhere on the board
!FRAM_CS: R11.1, U1.8 (PC5), U2.1 (!CS)
!FRAM_HOLD: R12.1, U1.13 (PC1), U2.7 (!HOLD)
!FRAM_WP: R13.1, U1.7 (PC6), U2.3 (!WP)
!RESET: J9.6 (!RESET), R10.1
ADE_CF: U1.6 (PC7); also elsewhere on the board
ADE_ZX: U1.5 (PB0); also elsewhere on the board
ANTENNA: A1.1, B1.1 (ANT)
BTLDR_CTRL: J9.5 (BL_CTRL), U1.18 (PA2/ROM-SSI-CLK)
BTLDR_RX: J9.4 (RX), U1.16 (PA0/ROM-UART-RX)
BTLDR_TX: J9.3 (TX), U1.17 (PA1/ROM-UART-TX)
GND: B1.2 (GND), B1.5 (GND), B1.6 (GND), C1.2, C2.2, C3.2, C4.2, C7.2, C11.2, C12.2, C13.2, C14.2, C15.2, C16.2, C17.2, C18.2, C19.2, C25.2, C26.2, C27.2, J9.2 (GND), R14.1, R17.2, TP1.TESTPOINT, U1.VSS_QFN (GND), U2.4 (VSS), X1.2 (GND), X1.4 (GND); also elsewhere on the board
GREEN_LED: D5.C, U1.22 (PA6)
MISO: U1.9 (PC4), U2.2 (SO); also elsewhere on the board
MOSI: U1.11 (PC3), U2.5 (SI); also elsewhere on the board
unnamed: C26.1, C27.1, U1.32 (DCOUPL2), U1.56 (DCOUPL1)
unnamed: C18.1, R10.2, U1.28 (!RESET)
unnamed: C4.1, U1.45 (PD7/XOSC32K_Q2), X2.2
unnamed: C3.1, U1.44 (PD6/XOSC32K_Q1), X2.1
unnamed: R17.1, U1.42 (R_BIAS)
unnamed: C1.1, U1.34 (XOSC32M_Q1), X1.1
unnamed: C2.1, U1.35 (XOSC32M_Q2), X1.3 (2)
unnamed: D6.A, R6.2
unnamed: D4.A, R4.2
unnamed: D5.A, R5.2
RED_LED: D4.C, U1.23 (PA7)
RELAY_CTRL: U1.50 (PB5); also elsewhere on the board
RELAY_LED: D6.C, U1.51 (PB4)
RF_N: B1.3 (BAL_N), U1.38 (RF_N)
RF_P: B1.4 (BAL_P), U1.37 (RF_P)
SCLK: U1.12 (PC2), U2.6 (SCK); also elsewhere on the board
TCK: TP14.TP, U1.47 (JTAG_TCK)
TDO: TP13.TP, U1.48 (PB7/JTAG-TDO)
TMS: TP12.TP, U1.46 (JTAG_TMS)
USER_RELAY_CTRL: R14.2, S1.P$2, S1.P$4, U1.52 (PB3)

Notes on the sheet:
PIN10
PIN15
PIN24
PIN55
PIN33
PIN36
PIN40
PIN43

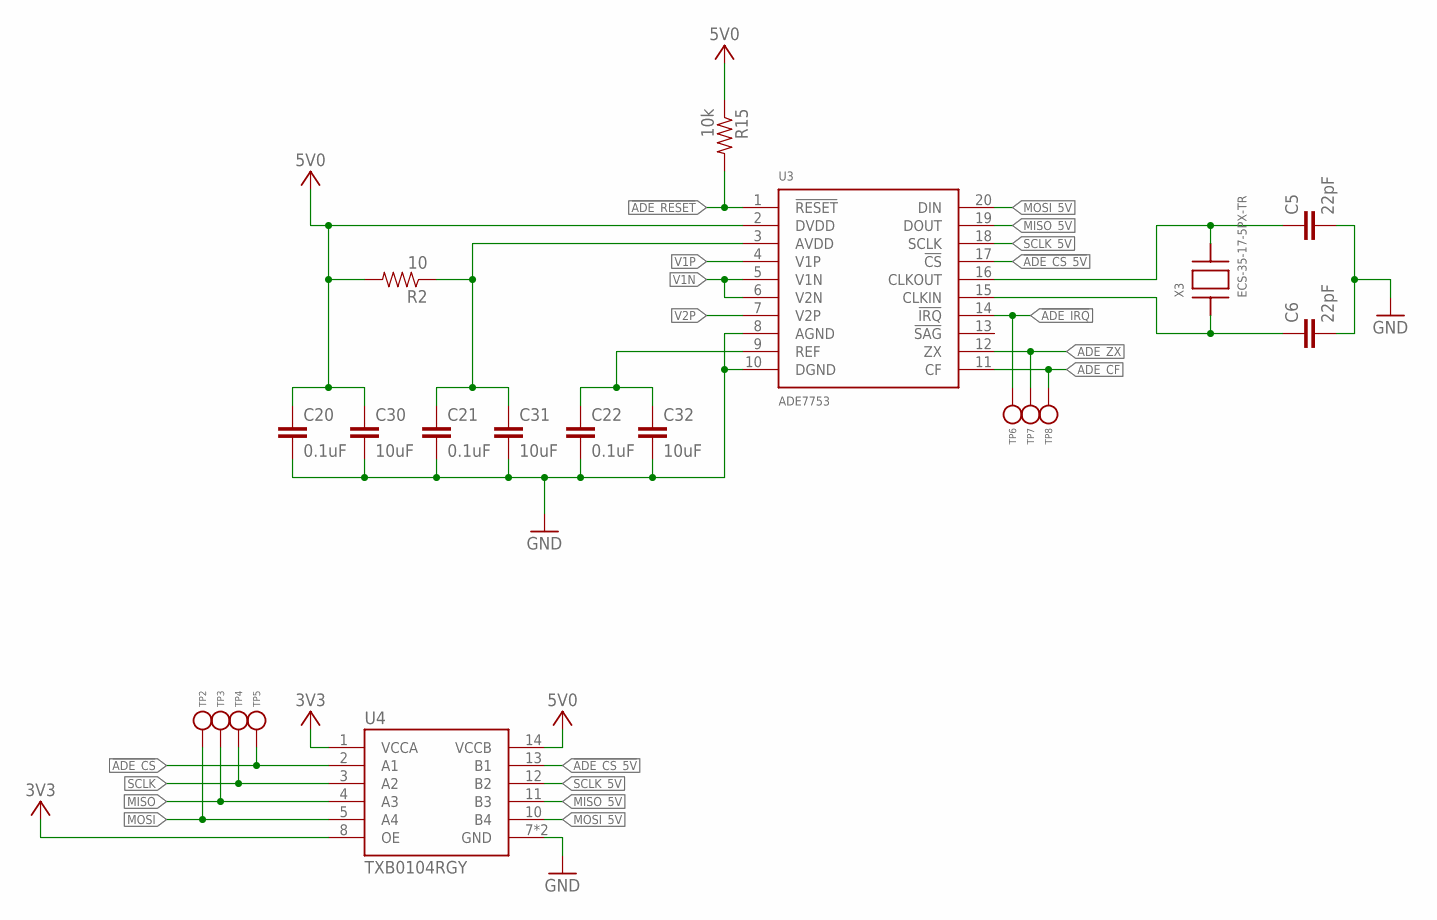
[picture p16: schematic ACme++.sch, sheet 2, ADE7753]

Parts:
C5, C6: 22pF; 0603-CAP; DIGIKEY 445-1273-1-ND
C20, C21, C22: 0.1uF; 0603-CAP; DIGIKEY 445-1316-1-ND
C30, C31, C32: 10uF; 0603-CAP; DIGIKEY 1276-1119-1-ND
R2: 10; 0603-RES; DIGIKEY RHM10.0CFCT-ND
R15: 10k; 0603-RES; DIGIKEY RHM10.0KCFCT-ND
TP2, TP3, TP4, TP5, TP6, TP7, TP8: TEST_POINT_0.040IN; TESTPOINT_0.040IN
U3: ADE7753; SSOP-20; MOUSER 584-ADE7753ARSZR
U4: TXB0104RGY; S-PVQFN-N14
X3: ECS-35-17-5PX-TR; CSM-7X

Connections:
3V3: U4.1 (VCCA), U4.8 (OE); also elsewhere on the board
5V0: C20.1, C30.1, R2.2, R15.1, U3.2 (DVDD), U4.14 (VCCB); also elsewhere on the board
!ADE_CS: TP5.TESTPOINT, U4.2 (A1); also elsewhere on the board
!ADE_CS_5V: U3.17 (!CS), U4.13 (B1)
!ADE_IRQ: TP6.TESTPOINT, U3.14 (!IRQ); also elsewhere on the board
!ADE_RESET: R15.2, U3.1 (!RESET)
ADE_AVDD: C21.1, C31.1, R2.1, U3.3 (AVDD)
ADE_CF: TP8.TESTPOINT, U3.11 (CF); also elsewhere on the board
ADE_ZX: TP7.TESTPOINT, U3.12 (ZX); also elsewhere on the board
GND: C5.2, C6.2, C20.2, C21.2, C22.2, C30.2, C31.2, C32.2, U3.8 (AGND), U3.10 (DGND), U4.7 (GND), U4.THERMALPAD (GND); also elsewhere on the board
MISO: TP3.TESTPOINT, U4.4 (A3); also elsewhere on the board
MISO_5V: U3.19 (DOUT), U4.11 (B3)
MOSI: TP2.TESTPOINT, U4.5 (A4); also elsewhere on the board
MOSI_5V: U3.20 (DIN), U4.10 (B4)
unnamed: C6.1, U3.15 (CLKIN), X3.1
unnamed: C22.1, C32.1, U3.9 (REF)
unnamed: C5.1, U3.16 (CLKOUT), X3.2
SCLK: TP4.TESTPOINT, U4.3 (A2); also elsewhere on the board
SCLK_5V: U3.18 (SCLK), U4.12 (B2)
V1N: U3.5 (V1N), U3.6 (V2N); also elsewhere on the board
V1P: U3.4 (V1P); also elsewhere on the board
V2P: U3.7 (V2P); also elsewhere on the board

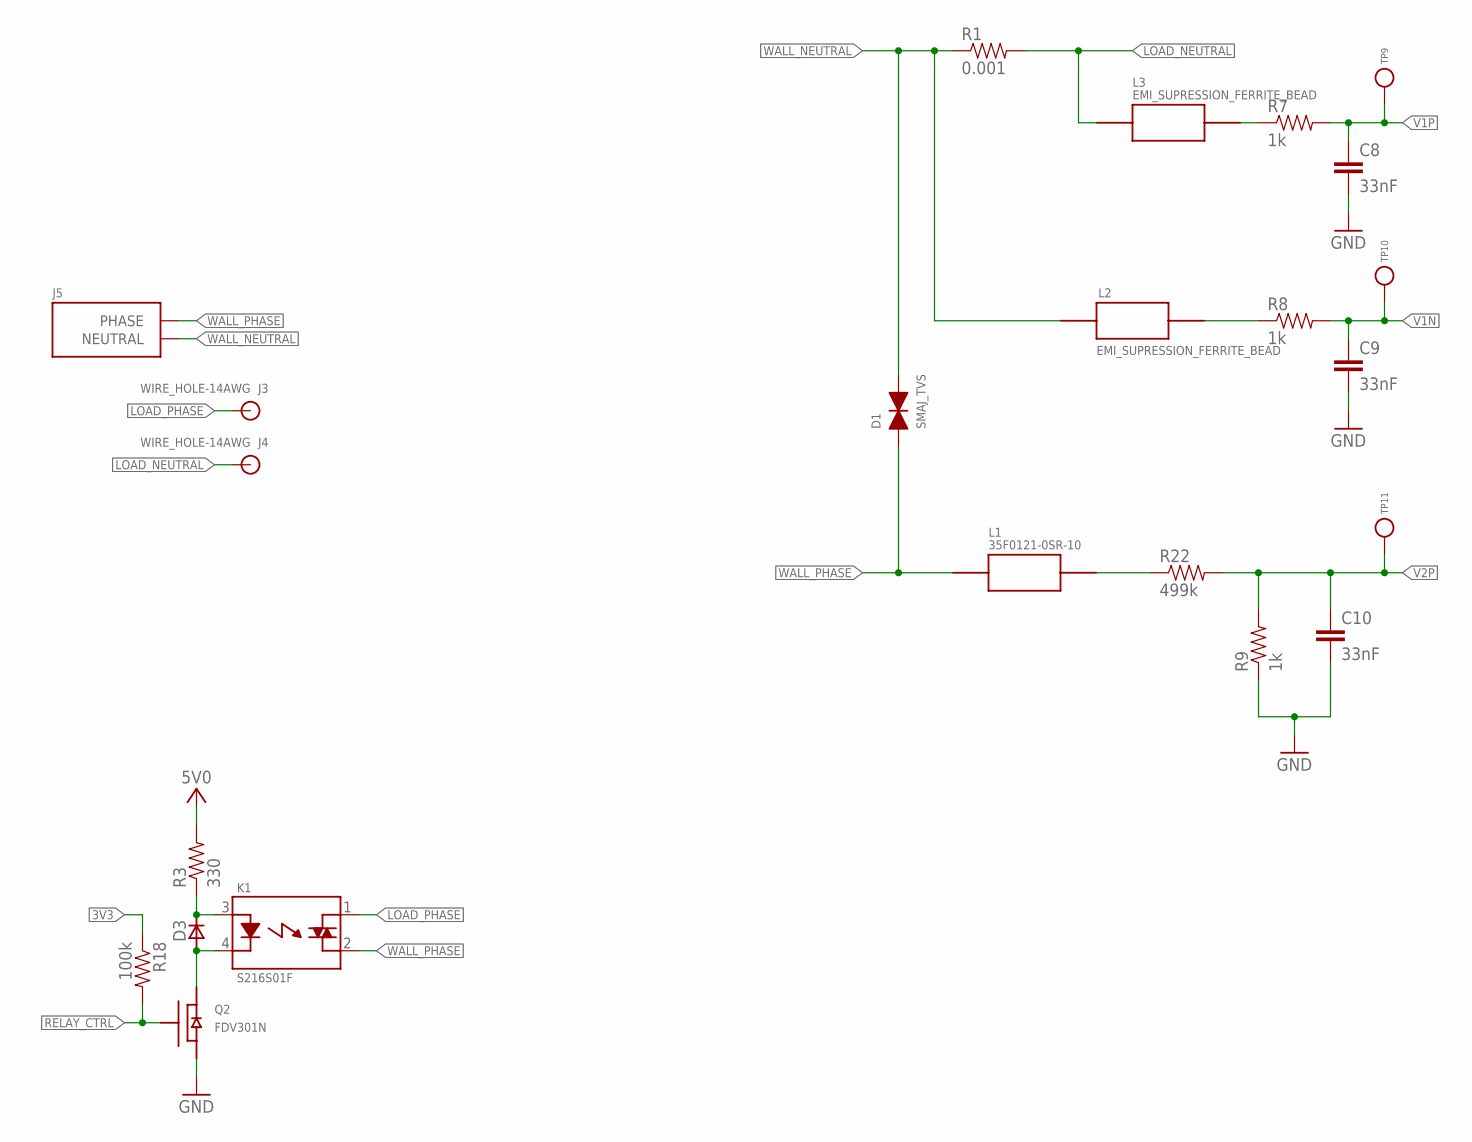
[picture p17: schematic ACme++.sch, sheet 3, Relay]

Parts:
C8, C9, C10: 33nF; 0805; DIGIKEY 478-1389-1-ND
D1: SMAJ_TVS; DO214_TVS
D3: DIODE_MMBD914; SOT-23
J3, J4: WIRE_HOLE-14AWG
J5: AC-PLUG-2; AC_MALE_PINS_2
K1: S216S01F; RELAY_SX16S0X
L1: 35F0121-0SR-10; 35F0102
L2, L3: EMI_SUPRESSION_FERRITE_BEAD; L1806
Q2: FDV301N; SOT-23
R1: 0.001; R2512; DIGIKEY P1.0TCT-ND
R3: 330; 0805; DIGIKEY RHM330KCT-ND
R7, R8, R9: 1k; 0805; DIGIKEY P16058CT-ND
R18: 100k; 0603-RES; DIGIKEY RHM100KCGCT-ND
R22: 499k; 0805; DIGIKEY P499KCCT-ND
TP9, TP10, TP11: TEST_POINT_0.040IN; TESTPOINT_0.040IN

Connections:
3V3: R18.1; also elsewhere on the board
5V0: R3.2; also elsewhere on the board
GND: C8.2, C9.2, C10.2, Q2.2 (S), R9.1; also elsewhere on the board
LOAD_NEUTRAL: J4.P$1, L3.P$1, R1.2
LOAD_PHASE: J3.P$1, K1.1
unnamed: D3.1 (ANNODE), K1.4, Q2.3 (D)
unnamed: D3.3 (CATHODE), K1.3, R3.1
unnamed: L2.P$2, R8.1
unnamed: L3.P$2, R7.1
unnamed: L1.2, R22.1
RELAY_CTRL: Q2.1 (G), R18.2; also elsewhere on the board
V1N: C9.1, R8.2, TP10.TESTPOINT; also elsewhere on the board
V1P: C8.1, R7.2, TP9.TESTPOINT; also elsewhere on the board
V2P: C10.1, R9.2, R22.2, TP11.TESTPOINT; also elsewhere on the board
WALL_NEUTRAL: D1.CATHODE, J5.NEUTRAL1 (NEUTRAL), J5.NEUTRAL2 (NEUTRAL), L2.P$1, R1.1; also elsewhere on the board
WALL_PHASE: D1.ANODE, J5.PHASE1 (PHASE), J5.PHASE2 (PHASE), K1.2, L1.1; also elsewhere on the board

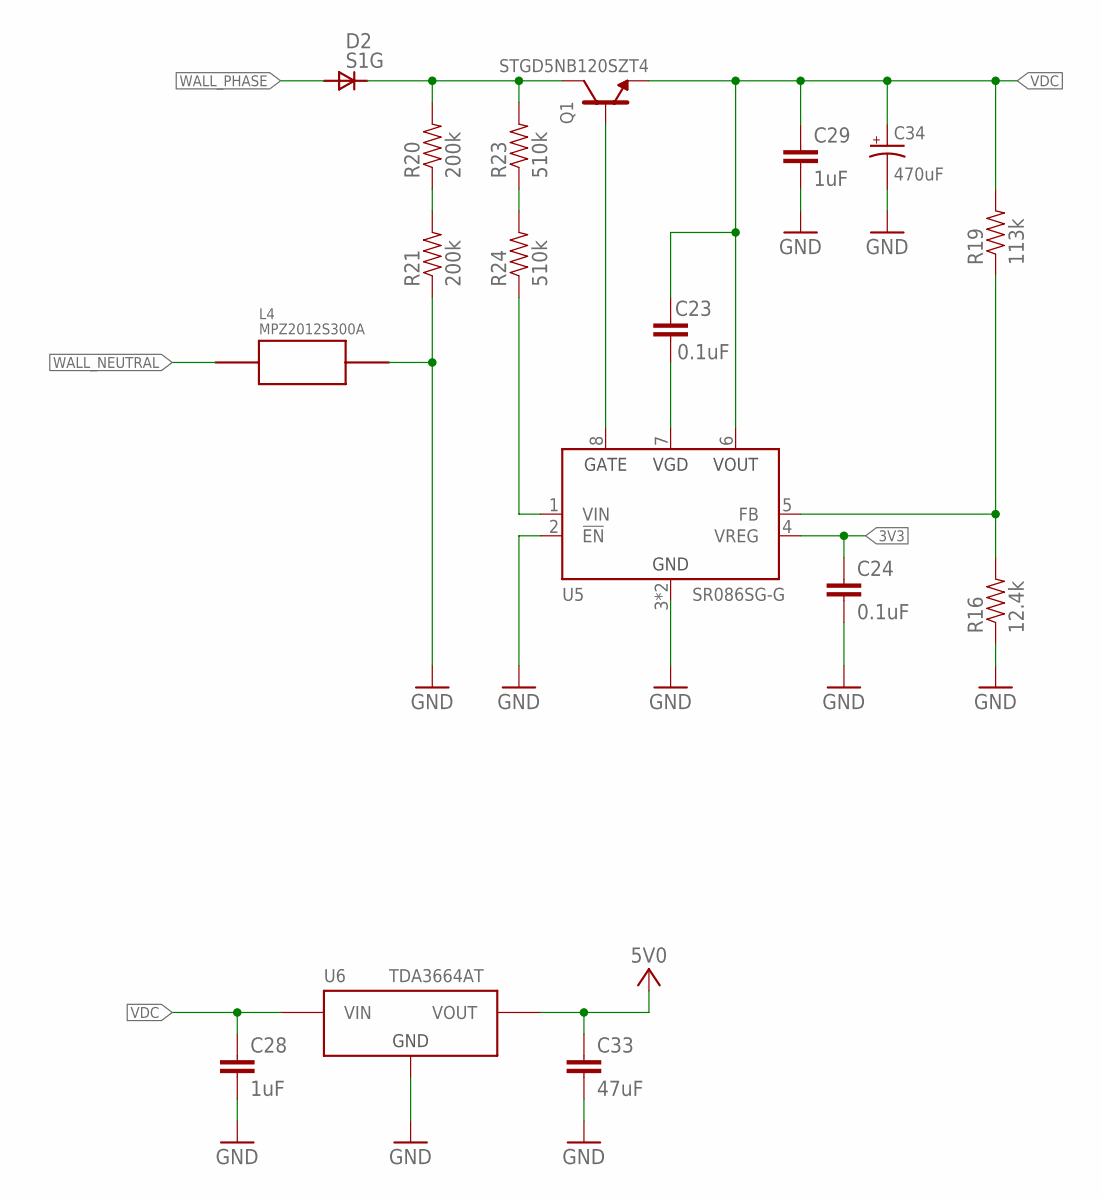
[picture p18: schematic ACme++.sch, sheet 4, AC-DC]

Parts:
C23, C24: 0.1uF; 0603-CAP; DIGIKEY 445-1316-1-ND
C28: 1uF; 0603-CAP; DIGIKEY 445-5956-1-ND
C29: 1uF; 1206; DIGIKEY 445-1381-1-ND
C33: 47uF; 1206; DIGIKEY 399-5508-1-ND
C34: 470uF; CAP_SM_10MM
D2: S1G; DO-214AC
L4: MPZ2012S300A; 0805_RESISTOR
Q1: STGD5NB120SZT4; DPAK
R16: 12.4k; 0603-RES; DIGIKEY RHM12.4KCFCT-ND
R19: 113k; 0603-RES; DIGIKEY RHM113KCFCT-ND
R20, R21: 200k; 1206; DIGIKEY P200KALCT-ND
R23, R24: 510k; 1206; DIGIKEY P510KALCT-ND
U5: SR086SG-G; SR086
U6: TDA3664AT; SOIC_8

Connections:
3V3: C24.1, U5.4 (VREG); also elsewhere on the board
5V0: C33.1, U6.1 (VOUT); also elsewhere on the board
DC_RECTIFIED: D2.CATHODE, Q1.P$2 (C), R20.2, R23.2
GND: C24.2, C28.2, C29.2, C33.2, C34.-, L4.P$2, R16.1, R21.1, U5.2 (!EN), U5.3 (GND), U5.PAD (GND), U6.3 (GND); also elsewhere on the board
unnamed: R20.1, R21.2
unnamed: R23.1, R24.2
unnamed: C23.2, U5.7 (VGD)
unnamed: R16.2, R19.1, U5.5 (FB)
SR086_GATE: Q1.P$1 (G), U5.8 (GATE)
SR086_VIN: R24.1, U5.1 (VIN)
VDC: C23.1, C28.1, C29.1, C34.+, Q1.P$3 (E), R19.2, U5.6 (VOUT), U6.8 (VIN)
WALL_NEUTRAL: L4.P$1; also elsewhere on the board
WALL_PHASE: D2.ANNODE; also elsewhere on the board

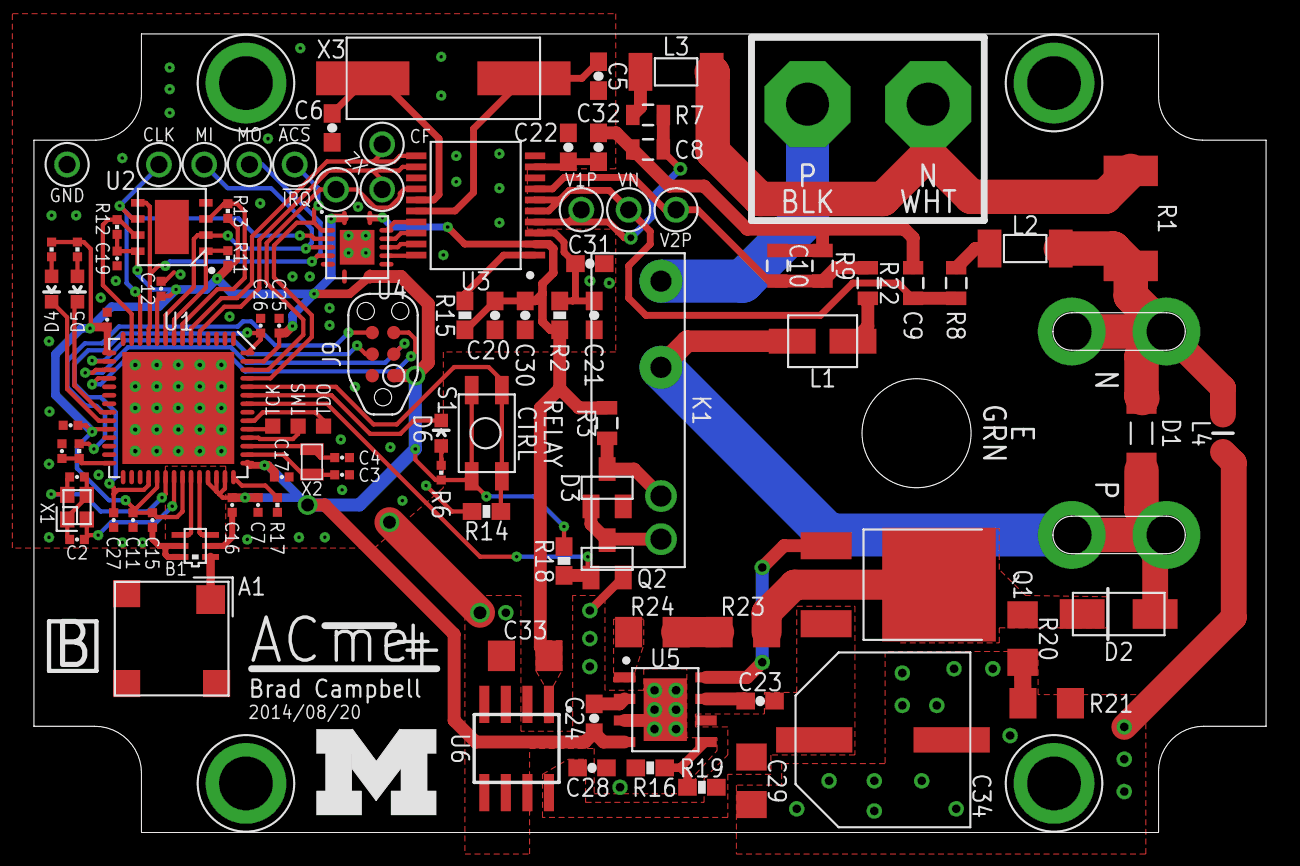
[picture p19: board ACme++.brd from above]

Board: 2 copper layers, 72.6 x 47.1 mm, 106 parts (0 on the bottom side), 67 nets.

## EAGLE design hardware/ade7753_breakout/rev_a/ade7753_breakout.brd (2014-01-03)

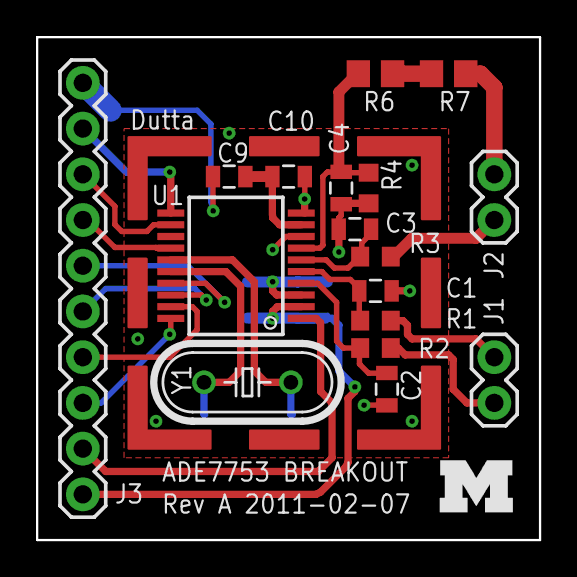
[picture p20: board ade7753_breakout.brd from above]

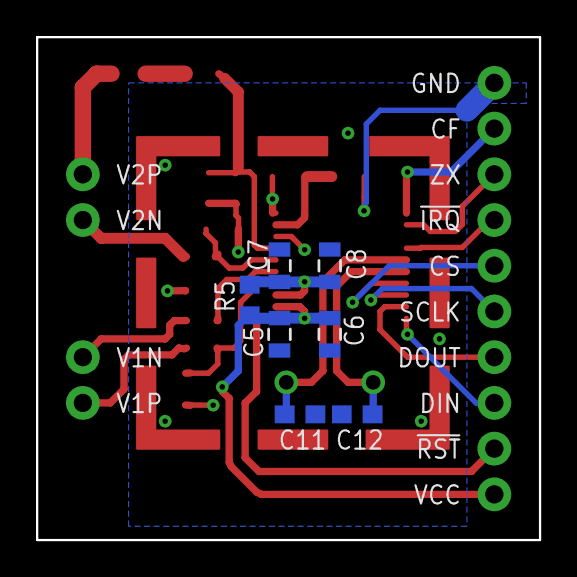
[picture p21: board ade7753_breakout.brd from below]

Board: 2 copper layers, 27.9 x 27.9 mm, 26 parts (7 on the bottom side), 23 nets.

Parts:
C1, C2, C3, C4: 33n; 0805
C5, C7, C9: 0.1u; 0805
C6, C8, C10: 10u; 0805
C11, C12: 22p; C0603
J1, J2: 1X02
J3: M10"; 1X10
R1, R2, R3, R4: 1k; R0603
R5: 10; R0603
R6, R7: 499k; R0805
U1: ADE7753; SSOP20
U$1: BLOCK-M
U$9: BMIS-202
Y1: 3.579 MHz; HC49/S

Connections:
GND: C1.2, C2.2, C3.2, C4.2, C5.2, C6.2, C7.2, C8.2, C9.2, C10.2, C11.2, C12.2, J3.10, R4.1, U1.8, U1.10
unnamed: J2.2, R7.1
unnamed: J1.1, R1.1
unnamed: J3.9, U1.11
unnamed: C4.1, R4.2, R6.2, U1.7
unnamed: C3.1, R3.2, U1.6
unnamed: C1.1, R1.2, U1.5
unnamed: R6.1, R7.2
unnamed: J1.2, R2.1
unnamed: J2.1, R3.1
unnamed: C2.1, R2.2, U1.4
unnamed: C9.1, C10.1, U1.9
unnamed: C11.1, U1.15, Y1.2
unnamed: C12.1, U1.16, Y1.1
unnamed: C7.1, C8.1, R5.1, U1.3
unnamed: C5.1, C6.1, J3.1, R5.2, U1.2
unnamed: J3.3, U1.20
unnamed: J3.4, U1.19
unnamed: J3.5, U1.18
unnamed: J3.6, U1.17
unnamed: J3.2, U1.1
unnamed: J3.7, U1.14
unnamed: J3.8, U1.12

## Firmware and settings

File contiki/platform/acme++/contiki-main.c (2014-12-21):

/**
 * \addtogroup platform
 * @{
 *
 * \defgroup acme++
 * @{
 *
 * \file
 *   Main module for the ACme++ platform
 */
/*---------------------------------------------------------------------------*/
#include "contiki.h"
#include "dev/leds.h"
#include "dev/sys-ctrl.h"
#include "dev/scb.h"
#include "dev/nvic.h"
#include "dev/uart.h"
#include "dev/watchdog.h"
#include "dev/ioc.h"
#include "dev/serial-line.h"
#include "dev/slip.h"
#include "dev/cc2538-rf.h"
#include "dev/udma.h"
#include "usb/usb-serial.h"
#include "lib/random.h"
#include "net/netstack.h"
#include "net/queuebuf.h"
#include "net/ip/uip.h"
#include "net/ip/tcpip.h"
#include "net/mac/frame802154.h"
#include "cpu.h"
#include "reg.h"
#include "ieee-addr.h"
#include "lpm.h"
#include "spi-arch.h"
#include "spi.h"
#include "fm25lb.h"
#include "ade7753.h"
#include "relay-button-sensor.h"
#include "mac_timer.h"

#include <stdint.h>
#include <string.h>
#include <stdio.h>
/*---------------------------------------------------------------------------*/
static void
set_rf_params(void)
{
    uint16_t short_addr;
    uint8_t ext_addr[8];

    ieee_addr_cpy_to(ext_addr, 8);

    short_addr = ext_addr[7];
    short_addr |= ext_addr[6] << 8;

    /* Populate linkaddr_node_addr. Maintain endianness */
    memcpy(&linkaddr_node_addr, &ext_addr[8 - LINKADDR_SIZE], LINKADDR_SIZE);

#if STARTUP_CONF_VERBOSE
    {
        int i;
        printf("Rime configured with address ");
        for(i = 0; i < LINKADDR_SIZE - 1; i++) {
            printf("%02x:", linkaddr_node_addr.u8[i]);
        }
        printf("%02x\n", linkaddr_node_addr.u8[i]);
    }
#endif

    NETSTACK_RADIO.set_value(RADIO_PARAM_PAN_ID, IEEE802154_PANID);
    NETSTACK_RADIO.set_value(RADIO_PARAM_16BIT_ADDR, short_addr);
    NETSTACK_RADIO.set_value(RADIO_PARAM_CHANNEL, CC2538_RF_CHANNEL);
    NETSTACK_RADIO.set_object(RADIO_PARAM_64BIT_ADDR, ext_addr, 8);
}
/*---------------------------------------------------------------------------*/
/**
 * \brief Main routine for the acme++ platform
 */
int
main(void)
{
  nvic_init();
  ioc_init();
  sys_ctrl_init();
  clock_init();
  lpm_init();
  rtimer_init();
  gpio_init();

  leds_init();
  leds_on(LEDS_ALL);

  process_init();

  watchdog_init();

  relay_button_sensor_init();

  spi_init();
  fm25lb_init();
  ade7753_init();

/*
#if UART_CONF_ENABLE
  uart_init();
  uart_set_input(serial_line_input_byte);
#endif

#if USB_SERIAL_CONF_ENABLE
  usb_serial_init();
  usb_serial_set_input(serial_line_input_byte);
#endif
*/
  serial_line_init();


  INTERRUPTS_ENABLE();

  /* Initialise the H/W RNG engine. */
  random_init(0);

  udma_init();

  process_start(&etimer_process, NULL);
  ctimer_init();

  set_rf_params();
  netstack_init();

#if NETSTACK_CONF_WITH_IPV6
  memcpy(&uip_lladdr.addr, &linkaddr_node_addr, sizeof(uip_lladdr.addr));
  queuebuf_init();
  process_start(&tcpip_process, NULL);
#endif /* NETSTACK_CONF_WITH_IPV6 */


  mac_timer_init();

  process_start(&sensors_process, NULL);

//  energest_init();
//  ENERGEST_ON(ENERGEST_TYPE_CPU);

  autostart_start(autostart_processes);

  watchdog_start();

  while(1) {
    uint8_t r;
    do {
      /* Reset watchdog and handle polls and events */
      watchdog_periodic();

      r = process_run();
    } while(r > 0);

    /* We have serviced all pending events. Enter a Low-Power mode. */
    lpm_enter();
  }
}
/*---------------------------------------------------------------------------*/

/**
 * @}
 * @}
 */

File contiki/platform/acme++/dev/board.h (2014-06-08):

/** \addtogroup cc2538
 * @{
 *
 * \defgroup acme++
 *
 * \note   Do not include this file directly. It gets included by contiki-conf
 *         after all relevant directives have been set.
 */
#ifndef BOARD_H_
#define BOARD_H_

#include "dev/gpio.h"
#include "dev/nvic.h"
/*---------------------------------------------------------------------------*/
/** \name SmartRF LED configuration
 *
 * LEDs on the SmartRF06 (EB and BB) are connected as follows:
 * - LED1 (Red)    -> PC0
 * - LED2 (Yellow) -> PC1
 * - LED3 (Green)  -> PC2
 * - LED4 (Orange) -> PC3
 *
 * LED1 shares the same pin with the USB pullup
 * @{
 */
/*---------------------------------------------------------------------------*/
/* Some files include leds.h before us, so we need to get rid of defaults in
 * leds.h before we provide correct definitions */
#undef LEDS_GREEN
#undef LEDS_YELLOW
#undef LEDS_RED
#undef LEDS_CONF_ALL

#define LEDS_BLUE                16 /**< PB4 */
#define LEDS_RED                 64 /**< PA6 */
#define LEDS_GREEN               128 /**< PA7 */
#define LEDS_CONF_ALL            208

/* Notify various examples that we have LEDs */
#define PLATFORM_HAS_LEDS        1

#define LED_BLUE_BASE            GPIO_B_BASE
#define LED_RED_BASE             GPIO_A_BASE
#define LED_GREEN_BASE           GPIO_A_BASE
#define LED_BLUE_MASK            GPIO_PIN_MASK(4)
#define LED_RED_MASK             GPIO_PIN_MASK(6)
#define LED_GREEN_MASK           GPIO_PIN_MASK(7)
/** @} */
/*---------------------------------------------------------------------------*/
/**
 * \name ADE7753 configuration
 *
 * These values configure which CC2538 pins to use for the ADE chip.
 * @{
 */
#define ADE7753_IRQ_N_PORT_NUM GPIO_B_NUM
#define ADE7753_IRQ_N_PIN      1
#define ADE7753_ZX_PORT_NUM    GPIO_B_NUM
#define ADE7753_ZX_PIN         0
#define ADE7753_CF_PORT_NUM    GPIO_C_NUM
#define ADE7753_CF_PIN         7
#define ADE7753_CS_N_PORT_NUM  GPIO_B_NUM
#define ADE7753_CS_N_PIN       2
/** @} */
/*---------------------------------------------------------------------------*/
/**
 * \name FM25LB configuration
 *
 * These values configure which CC2538 pins to use for the FRAM chip.
 * @{
 */
#define FM25LB_HOLD_N_PORT_NUM GPIO_C_NUM
#define FM25LB_HOLD_N_PIN      1
#define FM25LB_WP_N_PORT_NUM   GPIO_C_NUM
#define FM25LB_WP_N_PIN        6
#define FM25LB_CS_N_PORT_NUM   GPIO_C_NUM
#define FM25LB_CS_N_PIN        5
/** @} */
/*---------------------------------------------------------------------------*/
/**
 * \name SPI configuration
 *
 * These values configure which CC2538 pins to use for the SPI lines.
 * @{
 */
#define SPI_CLK_PORT  GPIO_C_NUM
#define SPI_CLK_PIN   2
#define SPI_MOSI_PORT GPIO_C_NUM
#define SPI_MOSI_PIN  3
#define SPI_MISO_PORT GPIO_C_NUM
#define SPI_MISO_PIN  4
/** @} */
/*---------------------------------------------------------------------------*/
/** \name GPIO
 *
 */
#define RELAY_CTRL_BASE          GPIO_B_BASE
#define RELAY_CTRL_MASK          GPIO_PIN_MASK(5)

#define RELAY_BUTTON_PORT        GPIO_B_NUM
#define RELAY_BUTTON_PIN         3
#define RELAY_BUTTON_VECTOR      NVIC_INT_GPIO_PORT_B
/** @} */
/*---------------------------------------------------------------------------*/
/** \name USB configuration
 *
 * The USB pullup is driven by PC0 and is shared with LED1
 */
#define USB_PULLUP_PORT          GPIO_C_BASE
#define USB_PULLUP_PIN           0
#define USB_PULLUP_PIN_MASK      (1 << USB_PULLUP_PIN)
/** @} */
/*---------------------------------------------------------------------------*/
/** \name UART configuration
 *
 * On the SmartRF06EB, the UART (XDS back channel) is connected to the
 * following ports/pins
 * - RX:  PA0
 * - TX:  PA1
 * - CTS: PB0 (Can only be used with UART1)
 * - RTS: PD3 (Can only be used with UART1)
 *
 * We configure the port to use UART0. To use UART1, replace UART0_* with
 * UART1_* below.
 * @{
 */
#define UART0_RX_PORT            GPIO_A_NUM
#define UART0_RX_PIN             0

#define UART0_TX_PORT            GPIO_A_NUM
#define UART0_TX_PIN             1
// unused uart1
#define UART1_CTS_PORT           GPIO_C_NUM
#define UART1_CTS_PIN            1

#define UART1_RTS_PORT           GPIO_C_NUM
#define UART1_RTS_PIN            2
/** @} */
/*---------------------------------------------------------------------------*/
/* Notify various examples that we do not have buttons */
#define PLATFORM_HAS_BUTTON      0
/** @} */
/*---------------------------------------------------------------------------*/
/**
 * \name Device string used on startup
 * @{
 */
#define BOARD_STRING "acme++"
/** @} */

#endif /* BOARD_H_ */

/**
 * @}
 * @}
 */

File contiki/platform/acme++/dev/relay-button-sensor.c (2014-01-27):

#include "contiki.h"
#include "dev/nvic.h"
#include "dev/ioc.h"
#include "dev/gpio.h"
#include "dev/relay-button-sensor.h"
#include "sys/timer.h"

#include <stdint.h>
#include <string.h>

#define RELAY_BUTTON_PORT_BASE  GPIO_PORT_TO_BASE(RELAY_BUTTON_PORT)
#define RELAY_BUTTON_PIN_MASK   GPIO_PIN_MASK(RELAY_BUTTON_PIN)
/*---------------------------------------------------------------------------*/
static struct timer debouncetimer;
/*---------------------------------------------------------------------------*/
/**
 * \brief Common initialiser for all buttons
 * \param port_base GPIO port's register offset
 * \param pin_mask Pin mask corresponding to the button's pin
 */
static void
config(uint32_t port_base, uint32_t pin_mask)
{
  /* Software controlled */
  GPIO_SOFTWARE_CONTROL(port_base, pin_mask);

  /* Set pin to input */
  GPIO_SET_INPUT(port_base, pin_mask);

  /* Enable edge detection */
  GPIO_DETECT_EDGE(port_base, pin_mask);

  /* Single edge */
  GPIO_TRIGGER_SINGLE_EDGE(port_base, pin_mask);

  /* Trigger interrupt on Falling edge */
  GPIO_DETECT_RISING(port_base, pin_mask);

  GPIO_ENABLE_INTERRUPT(port_base, pin_mask);
}
/*---------------------------------------------------------------------------*/
/**
 * \brief Callback registered with the GPIO module. Gets fired with a button
 * port/pin generates an interrupt
 * \param port The port number that generated the interrupt
 * \param pin The pin number that generated the interrupt. This is the pin
 * absolute number (i.e. 0, 1, ..., 7), not a mask
 */
static void
btn_callback(uint8_t port, uint8_t pin)
{
  /* Check if the debounce timer is still active. If so, skip this button
     press. */
  if (!timer_expired(&debouncetimer)) {
    return;
  }

  /* Start the timer to ignore any upcoming bounces */
  timer_set(&debouncetimer, CLOCK_SECOND / 8);

  /* Make sure that we should notify upper level applications */
  if (port == RELAY_BUTTON_PORT && pin == RELAY_BUTTON_PIN) {
    sensors_changed(&relay_button_sensor);
  }
}
/*---------------------------------------------------------------------------*/
/**
 * \brief Init function for the select button.
 *
 * Parameters are ignored. They have been included because the prototype is
 * dictated by the core sensor api. The return value is also not required by
 * the API but otherwise ignored.
 *
 * \param type ignored
 * \param value ignored
 * \return ignored
 */
static int
config_relay_button(int type, int value)
{
  config(RELAY_BUTTON_PORT_BASE, RELAY_BUTTON_PIN_MASK);

  ioc_set_over(RELAY_BUTTON_PORT, RELAY_BUTTON_PIN, IOC_OVERRIDE_PUE);

  nvic_interrupt_enable(RELAY_BUTTON_VECTOR);

  gpio_register_callback(btn_callback, RELAY_BUTTON_PORT, RELAY_BUTTON_PIN);
  return 1;
}
/*---------------------------------------------------------------------------*/
void
relay_button_sensor_init()
{
  timer_set(&debouncetimer, 0);
}
/*---------------------------------------------------------------------------*/
SENSORS_SENSOR(relay_button_sensor, BUTTON_SENSOR, NULL, config_relay_button, NULL);

/** @} */

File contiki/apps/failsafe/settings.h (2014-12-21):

#ifndef __SETTINGS_H__
#define __SETTINGS_H__

#include <stdint.h>

// Constant to keep track of which revision of coilcube sent the packet.
// This will probably be useful to determine what wakeups and packets mean.
//#define SEHNSOR_VERSION 2

#define ADDR_ALL_ROUTERS "ff02::2"

#define GATD_ADDR "2001:470:1f10:1320::2"
#define GATD_PORT 4001

#define MAGICID 0xBD30

#define FRAM_ADDR_CONFIG 0

typedef struct {
  uint32_t magic_id;
  uint8_t power_state;
} fram_config_t;


#define RELAY_OFF 0
#define RELAY_ON  1

#define ACME_CMD_POWER_ON  1
#define ACME_CMD_POWER_OFF 2


#define UDP_LISTEN_PORT 47652
#define UDP_REMOTE_PORT 47653

#endif

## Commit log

2013-12-19 start of acme++
    [ACme++.brd, ACme++.sch]
2013-12-19 working on relay
    [ACme++.brd, ACme++.sch]
2013-12-20 working on ac connections
    [ACme++.brd, ACme++.sch]
2013-12-24 power supplies fleshed out
    [ACme++.brd, ACme++.sch]
2013-12-24 progress
    cleaned up schematic a bit
    initial arragnment on pcb
    [ACme++.brd, ACme++.sch]
2013-12-24 working on routing
    power supply laid out
    working on ace
    lots of room...put cc2538 on this board? hard to argue not to...
    [ACme++.brd, ACme++.sch]
2013-12-24 routing the cc2538
    [ACme++.brd, ACme++.sch]
2013-12-25 working on ground plane
    man there are some rediculous traces for this cc2538
    [ACme++.brd, ACme++.sch]
2013-12-25 routed.
    still not sure what to do with "GND" for the differential signals
    running to the ade
    [ACme++.brd, ACme++.sch]
2013-12-25 routing and labeling
    [ACme++.brd, ACme++.sch]
2013-12-26 added labels to schematic
    [ACme++.brd, ACme++.sch]
2013-12-26 changed gnd and routed
    made the gnd for the ade measurement signals the emi filtered neutral
    from the wall. As best as I can tell this is was acme does. Updated that
    on the schematic and routed it.
    [ACme++.brd, ACme++.sch]
2013-12-26 added regulator datasheet
2013-12-26 thinking about ac lines, tantalum caps
    [ACme++.brd]
2013-12-26 routed ac under board, renamed
    did my thing where part numbers correspond to values
    [ACme++.brd, ACme++.sch]
2013-12-26 added bom
    [ACme_bom.xlsx]
2013-12-26 renamed bom
    [ACme++_bom.xlsx]
2013-12-26 routed the new sparkfun resistors
    I changed over to all sparkfun so had to swap out some parts
    [ACme++.brd]
2013-12-26 updated bom
    [ACme++_bom.xlsx]
2013-12-26 more clearance for phase
    [ACme++.brd]
2013-12-26 moved rev letter
    [ACme++.brd]
2013-12-26 clean silkscreen
    [ACme++.brd]
2013-12-27 more bom cleaning
    [ACme++_bom.xlsx]
2013-12-27 added non pcb items to bom
    [ACme++.brd, ACme++_bom.xlsx]
2013-12-27 added new layers
    These layers are for names (top and bot) that should be there for
    assembly but shouldn't be on the board (ie they just dont fit).
    Moved everthing that was on Reference to tNamesHiddem
    [ACme++.brd]
2014-01-03 moved prabal's ade breakout
    Still trying to get rid of that dropbox eagle folder.
    [ade7753_breakout.brd, ade7753_breakout.sch, ade7753_breakout_bom.xlsx]
2014-01-03 updates to acme++
    - no plated earth gnd
    - added test points
    [ACme++.brd, ACme++.sch]
2014-01-03 moved relay back
    [ACme++.brd]
2014-01-05 worked on plated cutouts...
    I hope sunstone will do something reasonable
    [ACme++.brd, ACme++.sch]
2014-01-06 added interrupt register values
2014-01-06 broke up write to mode reg into bytes
    [ade7753.c]
2014-01-07 moved phase trace
    [ACme++.brd]
2014-01-07 changing 14awg holes
    [ACme++.brd, ACme++.sch]
2014-01-07 moved silkscreen
    [ACme++.brd]
2014-01-07 more documentation for acme++
    [ACme++_bom.csv, ACme++_bom.xlsx]
2014-01-07 formatting bom, added test points
    [ACme++_bom.xlsx]
2014-01-08 fabbing acme++ rev a
    [ACme++_bom.csv]
2014-01-27 button works
2014-01-29 added led toggle and timer to ade test code
2014-01-29 switched msb and lsb in ade mode write
2014-02-12 fixed messageLen issue in adeReadReg
    [ade7753.c]
2014-02-24 new app that is just a wireless switch
2014-02-26 fixed leds
    they were backwards before (on was off)
2014-03-06 updated acme_switch app to work with borderrouter
    corrected udp calls
    need my changes to contiki
    [acme_switch.c, contiki-conf.h]
2014-03-07 added memory for power state
    stored in fram
2014-03-18 Updated FRAM driver
    Now uses better spi driver and has a lot less crap in it
2014-03-27 updates to powercube
2014-05-21 updates to voltage virtualization app
2014-06-08 acme app working with current contiki
2014-08-13 updated acme++
    - removed ds2411
    - updated programmer to bootloader based version
    - moved leds
    - add holes with metal
    [ACme++.brd, ACme++.sch]
2014-08-20 acme ++ rev b changes
    [ACme++.brd, ACme++.sch]
2014-08-29 new version of acme++
    [ACme++.brd, ACme++.sch, ACme++_bom.csv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]
2014-12-21 acme switch with coap!
2014-12-21 added failsafe app
    turns acme++ back on
    [failsafe.c, project-conf.h, settings.h]

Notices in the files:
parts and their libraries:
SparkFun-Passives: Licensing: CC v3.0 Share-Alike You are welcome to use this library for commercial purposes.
